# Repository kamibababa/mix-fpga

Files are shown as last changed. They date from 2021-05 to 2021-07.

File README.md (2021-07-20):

# MIX-fpga

Have you ever heard of Don Knuths (hypothetical) first polyunsaturated computer MIX, the 1009? In this project we will build a binary version of the MIX-Computer as described in "The Art of Computer Programming, Vol. 1" by Donald E. Knuth running on an fpga-board.

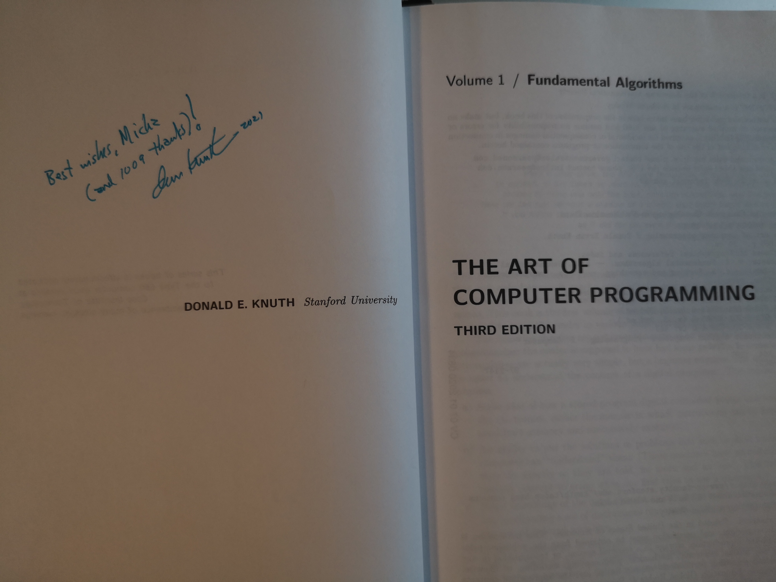
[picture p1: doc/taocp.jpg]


The presented implementation is based on the fpga development board iCE40HX8K-EVB from the company Olimex Ltd., which has the nice property of being completely open source. The whole project uses only FOSS free and open source hard- and software, so everybody can build their own MIX following the instructions in `build`.

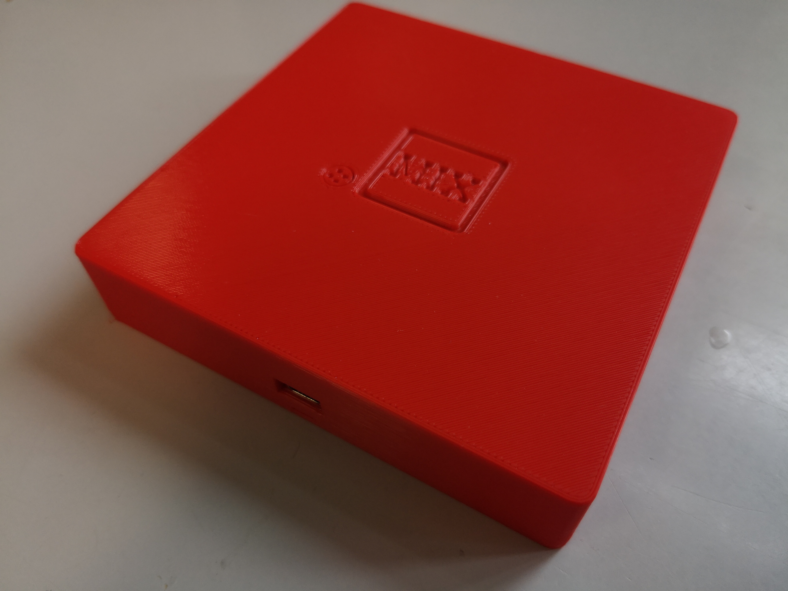
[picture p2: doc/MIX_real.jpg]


## A look Inside

The MIX computer is composed of two little boards:

1. iCE40HX8K-EVB, the fpga development board from olimex.com
2. USB-serial adapter. Used to power the board with 5V and to in-/output data over serial interface.

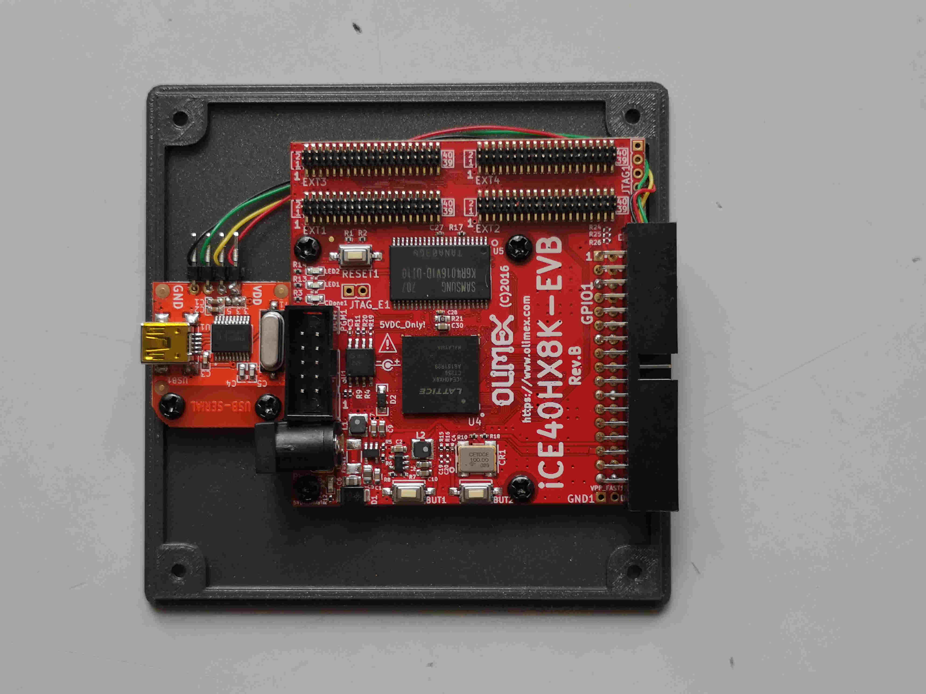
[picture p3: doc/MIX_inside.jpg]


### Basic unit of time
MIX runs on iCE40HX8K-EVB clocked at 23.8MHz. The basic unit of time 1u corresponds to 42ns, so according to Knuth it's a relatively high priced machine.

### Character based I/O units U16-U20
In our MIX implementation all character based I/O units (U16 -- U20) are connected to the USB-connector and can be accessed as serial data streams. You can connect MIX with any PC running a terminal emulator (e.g. screen for linux). The terminal should be set to 115200 baud (8N1). A conversion between ASCII and Knuths character codes is done in hardware according to Knuths specification (see TAOCP p. 128).

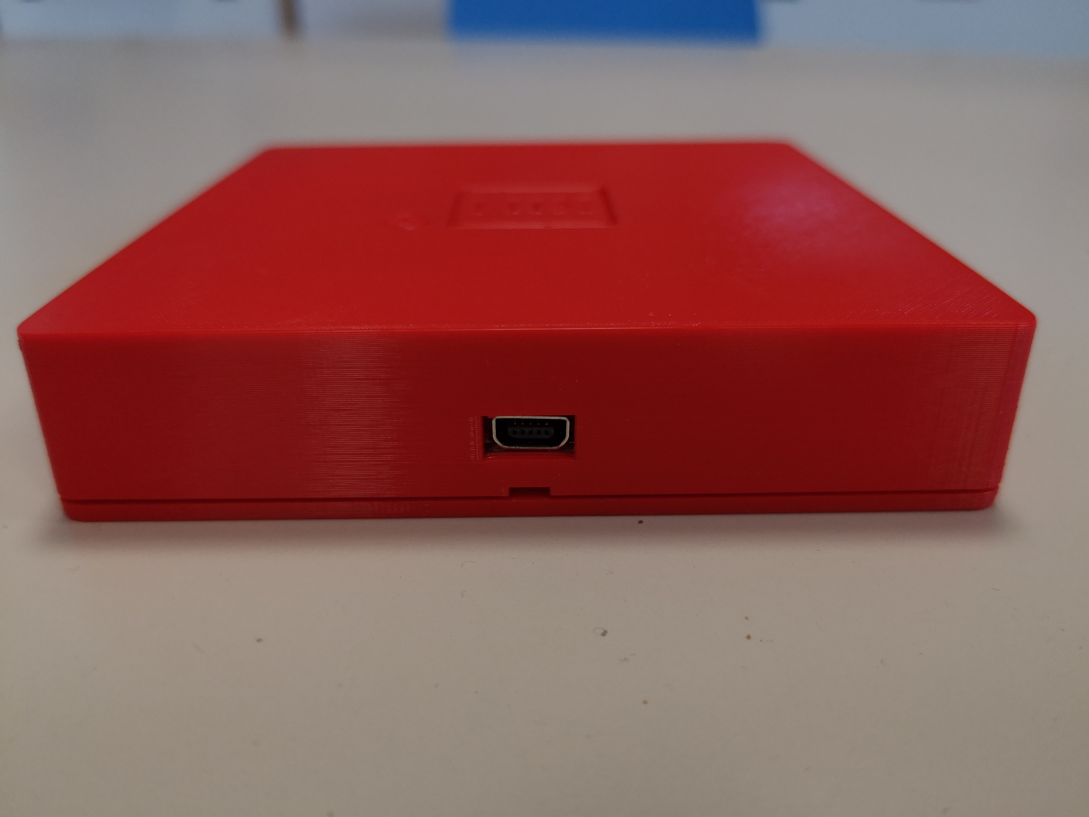
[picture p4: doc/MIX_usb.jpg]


### The block based I/O unit U0
A block based device is implemented on I/O unit 0. The device acts as a tape with 1024 blocks à 100 words. The data is stored in the SRAM chip included on the iCE40HX8K-EVB board. The speed of read and write operations is exactly 401u for reading or writing one complete block of data (no JBUS is needed). The data stored to unit U0 can be retrieved also after a reset (GO-Button). But on a full shutdown, when removing power supply (USB connector) data is lost.

### Commands
All commands described in TAOCP Vol. 1 are implemented (s. list) with execution times corresponding to Knuth's specifications. Special care is given to the correct timings. Even the "sofisticated" commands SRC and SLC, which need a modulo 10 computation are executed in the defined timing of two cycles.

| Command | OP  | Field | Timing |
| ---|-----|---|---|
| NOP | 0 | 0 | 1u |
| ADD, SUB, MUL, DIV | 1, 2, 3, 4 | 0:5 | 2u, 2u, 10u, 12u |
| FADD, FSUB, FMUL, FDIV | 1, 2, 3, 4 | 6 | 4u, 4u, 9u, 11u |
| NUM, CHAR| 5 | 0, 1 | 10u |
| HLT | 5 | 2 | ? |
| SLA, SRA, SLAX, SRAX, SLC, SRC| 6  | 0--5|  2u |
| MOVE | 7 | F | (1+2F)u|
| LDr | 8--15| 0:5 | 2u |
| LDNr |16--23| 0:5 | 2u |
| STr |24--31| 0:5 | 2u |
| STJ | 32  | 0:2 | 2u |
| STZ | 33  | 0:5 | 2u |
|JBUS, JRED|34,38| U | 1u |
| IOC | 35  | U | 1u |
| IN, OUT  |36,37| U | (1+T)u |
| JMP, JSJ, JOV, JNOV, JL, JE, JG, JGE, JNE, JLE| 39  |0--9  | 1u | 
| JrN, JrZ, JrP, JrNN, JrNZ, JrNP, JrE, JrO | 40--47| 0--7 | 1u |
| INCr, DECr, ENTr, ENNr  | 48--53 |0--3 | 1u |
| CMPr|54--63|0:5 | 2u |

The system can (easily) be extended in various ways:

1. add more commands:
	* logic operators: AND, OR, XOR, NOT (to do)
	* JrE,JrO jump if Register r is even/odd (done)
	* Floating point arithmetic: FADD, FSUB, FMUL, FDIV (done)
	* Floating point compare: FCMP (to do)
2. add more hardware:
	* add leds to run the traffic light example (done)
	* add block I/O unit (done)

### The GO button
MIX comes with the "GO button" attached to USB-UART. So after pressing the GO button MIX-programms can be uploaded by sending the "punched cards" to USB-UART.

### Toast case
MIX fits in a nice case with formfactor of a slice of toast, so your complete MIX computer system will easily fit into your lunch box. The case can be printed with a 3D printer. Design files can be found in the directory `build/toast`.

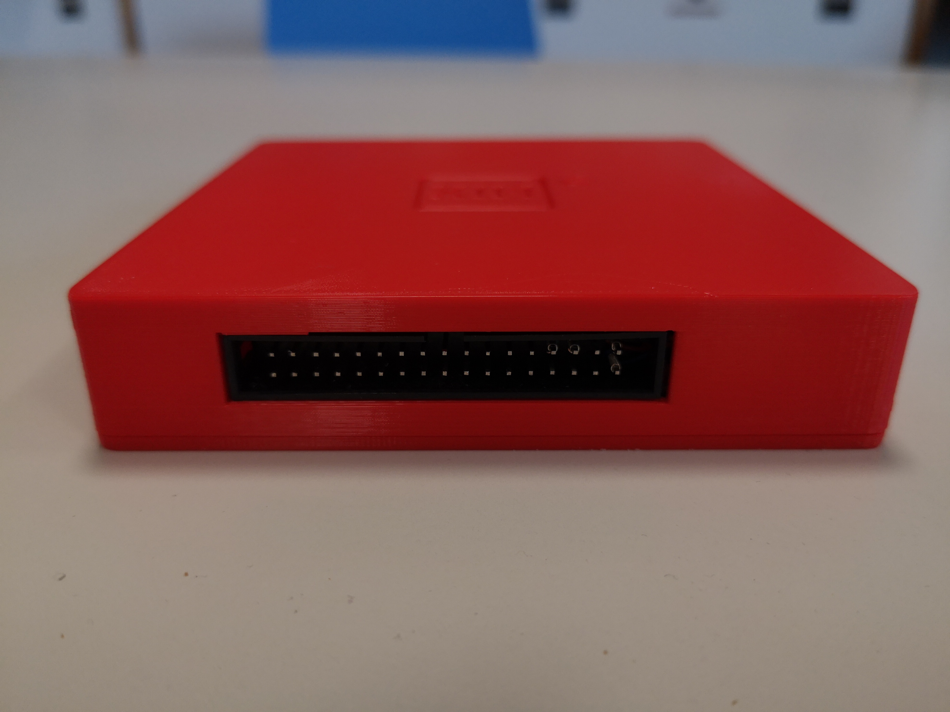
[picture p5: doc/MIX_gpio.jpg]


### Verify

MIX has been verified with the following programms. The numbering correspond to the sections in TAOCP.

* **1.3.1ex26** card-loading routine
* **1.3.2P** table of primes
* **1.3.2E** easter dates
* **1.3.2.ex13** cryptanalyst problem (classified)
* **1.3.2.ex16** sum of harmonic series
* **1.3.2.ex20** josephus problem
* **1.3.2.ex22** traffic signal problem (driving real LEDs)
* **1.3.3A** multiply permutations in cycle form
* **1.4.2**  character input routine
* **1.4.3** tracing routine (uses tape U0)
* **2.2.5elevator** elevator simulation (with added in-/output)
* **mixaload** A load and go assembler by James L. Peterson from [Computer Organization and Assembly Language Programming](http://www.jklp.org/profession/books/mix/index.html)

### Example 1: Program 1.3.2P
Compute the first 500 primes
	
```
FIRST FIVE HUNDRED PRIMES                                                 
     0002 0233 0547 0877 1229 1597 1993 2371 2749 3187                    
     0003 0239 0557 0881 1231 1601 1997 2377 2753 3191                    
     0005 0241 0563 0883 1237 1607 1999 2381 2767 3203                    
     0007 0251 0569 0887 1249 1609 2003 2383 2777 3209                    
     0011 0257 0571 0907 1259 1613 2011 2389 2789 3217                    
     0013 0263 0577 0911 1277 1619 2017 2393 2791 3221                    
     0017 0269 0587 0919 1279 1621 2027 2399 2797 3229                    
     0019 0271 0593 0929 1283 1627 2029 2411 2801 3251                    
     0023 0277 0599 0937 1289 1637 2039 2417 2803 3253                    
     0029 0281 0601 0941 1291 1657 2053 2423 2819 3257                    
     0031 0283 0607 0947 1297 1663 2063 2437 2833 3259                    
     0037 0293 0613 0953 1301 1667 2069 2441 2837 3271                    
     0041 0307 0617 0967 1303 1669 2081 2447 2843 3299                    
     0043 0311 0619 0971 1307 1693 2083 2459 2851 3301                    
     0047 0313 0631 0977 1319 1697 2087 2467 2857 3307                    
     0053 0317 0641 0983 1321 1699 2089 2473 2861 3313                    
     0059 0331 0643 0991 1327 1709 2099 2477 2879 3319                    
     0061 0337 0647 0997 1361 1721 2111 2503 2887 3323                    
     0067 0347 0653 1009 1367 1723 2113 2521 2897 3329                    
     0071 0349 0659 1013 1373 1733 2129 2531 2903 3331                    
     0073 0353 0661 1019 1381 1741 2131 2539 2909 3343                    
     0079 0359 0673 1021 1399 1747 2137 2543 2917 3347                    
     0083 0367 0677 1031 1409 1753 2141 2549 2927 3359                    
     0089 0373 0683 1033 1423 1759 2143 2551 2939 3361                    
     0097 0379 0691 1039 1427 1777 2153 2557 2953 3371                    
     0101 0383 0701 1049 1429 1783 2161 2579 2957 3373                    
     0103 0389 0709 1051 1433 1787 2179 2591 2963 3389                    
     0107 0397 0719 1061 1439 1789 2203 2593 2969 3391                    
     0109 0401 0727 1063 1447 1801 2207 2609 2971 3407                    
     0113 0409 0733 1069 1451 1811 2213 2617 2999 3413                    
     0127 0419 0739 1087 1453 1823 2221 2621 3001 3433                    
     0131 0421 0743 1091 1459 1831 2237 2633 3011 3449                    
     0137 0431 0751 1093 1471 1847 2239 2647 3019 3457                    
     0139 0433 0757 1097 1481 1861 2243 2657 3023 3461                    
     0149 0439 0761 1103 1483 1867 2251 2659 3037 3463                    
     0151 0443 0769 1109 1487 1871 2267 2663 3041 3467                    
     0157 0449 0773 1117 1489 1873 2269 2671 3049 3469                    
     0163 0457 0787 1123 1493 1877 2273 2677 3061 3491                    
     0167 0461 0797 1129 1499 1879 2281 2683 3067 3499                    
     0173 0463 0809 1151 1511 1889 2287 2687 3079 3511                    
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
```
			
### Example 2: Program 1.3.2.ex22
MIX can control the traffic signal of the corner del Mar Avenue/Berkeley Avenue. MIX is NOT a simulatin/emulation. It's real hardware. So you can drive the LEDs with the output of RegisterX. Input is done with a push button, which directly connects to the overflow toggle.

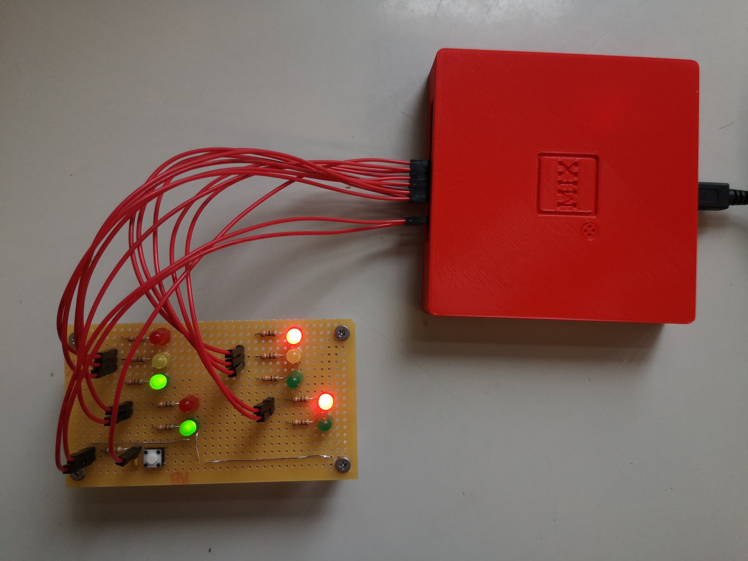
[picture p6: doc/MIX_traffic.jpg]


## need help?
In case you find encounter an issue with MIX`:

* don't panic
* send an email to mi.schroeder@netcologne.de

## related links

* [The Art of Computer Programming](https://www-cs-faculty.stanford.edu/~knuth/taocp.html): Donald Knuth's homepage

* [The Art of FPGAs: MIX-FPGA](https://www.hackster.io/news/the-art-of-fpgas-mix-fpga-edc1a7e47939): Article of Whitney Knitter on hackster.io

* [Computer Organization and Assembly Language Programming](http://www.jklp.org/profession/books/mix/index.html) by James L. Peterson

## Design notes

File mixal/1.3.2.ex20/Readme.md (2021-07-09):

# Running program t on MIX
We will run programm t of exercise 20 in chapter 1.3.2 TAOCP (p. 161) on MIX. Programm t controls the traffic signal at corner of Del Mare Boulevard and Berkeley Avenue. This project will connect LEDs directly to the register rX and a push button to the  Overflow toggle. This will be done extending the fpga design and routing the appropriate signals to the GPIO connector at the back of MIX.



## Extending the fpga desing
Make a copy of the folder `rtl` and cd into it.
```
cd build
cp -r rtl rtl_traffic_light
cd rtl_traffic_light
```
### mix.pcf
Add the following lines to physical constraint file `mix.pcf`:

```
#at the GPIO connector you find
set_io rx 		E4	# GPIO 5
set_io tx 		B2	# GPIO 7
set_io dmred 	F5	# GPIO 9
set_io bred 	J2	# GPIO 10
set_io dmamber 	B1	# GPIO 11
set_io bamber 	H1	# GPIO 12
set_io dmgreen 	C1	# GPIO 13
set_io bgreen 	G1	# GPIO 14
set_io dmdw 	C2	# GPIO 15
set_io bdw 		J5	# GPIO 16
set_io dmw 		F4	# GPIO 17
set_io bw 		H2	# GPIO 18
set_io button 	D2	# GPIO 19
```

### mix.v
Add the following lines to the hardware description file `mix.v` to connect the Register rX with the traffic signals.

```
	assign dmgreen = RegisterX[19:18] == 2'd1;
	assign dmamber = RegisterX[19:18] == 2'd2;
	assign dmred = RegisterX[19:18] == 2'd3;
	assign bgreen = RegisterX[13:12] == 2'd1;
	assign bamber = RegisterX[13:12] == 2'd2;
	assign bred = RegisterX[13:12] == 2'd3;
	assign dmw = RegisterX[7:6] == 2'd1;
	assign dmdw = RegisterX[7:6] == 2'd2;
	assign bw = RegisterX[1:0] == 2'd1;
	assign bdw = RegisterX[1:0] == 2'd2;
```

Find the code snipped that controls the overflow toggle and add the line commented with "# traffic signal button". 

```
always @(posedge clk)
		if (reset) overflow <= 0;
		else if (button) overflow <= 1;		# traffic signal button
		else if (add2) overflow <= addof;
		else if (sub2) overflow <= subof;
		else if (ide) overflow <= (rA|rX)? ideout[30] : ideout[12];

```
### rebuild and flash to iCE40HX8K-EVB

* Rebuild the fpga project and upload. `apio clean` is needed, because otherwise the the preloaded memory will not be updated.
	```
	apio clean
	apio build -v
	apio upload
	```
	
	Tipp: change the welcome message to ensure the new rom file has been uploaded.
	
### leds and button
Connect leds and button (don't forget resistors) to the appropriate GPIO connectors as described in the `mix.pcf` file. For simplicity only one LED is shown below:

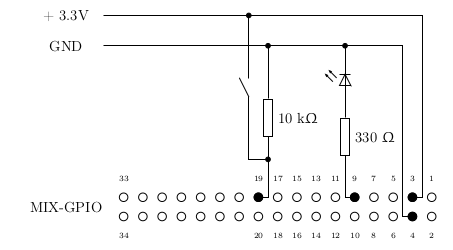
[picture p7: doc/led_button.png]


**Attention:** gpio pins 1,2,5 and 7 are already used by the internal USB-serial converter. 

### t.mixal
Compile t.mixal, upload to MIX and run the traffic signals.

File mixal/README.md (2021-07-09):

## Running programs on MIX

### tools
To run MIXAL programs on MIX the following tools found in `tools` are needed:

* `asm.py`: translates the mixal program into numeric representation (.mls).

* `mls2card.py` : translate the machine code (.mls) to punchcard format. The first two cards beeing the loading routine (1.3.1.ex26) and the last card beeing the transfer card.

* `mls2char.py` : translate to character codes, which can directly be read by MIX. (This is only necessary for the card-loading routine written on the first two punch cards).

* `mls2bin.py`: translate the .mls file to binary. This is only necessary for the GO button, which is hardcoded into fpga ROM.

### V1: Upload and run in a screen session
Finally you can connect your PC to MIX with a USB cable and start the  terminal emulator (```screen```):

```
$ screen /dev/ttyUSB0 115200
```

Press the GO button to start MIX. You should see the MIX welcome message:

```
WELCOME TO MIX. 1U = 40NS. U16-U20 TO UART @115200 BAUD (8N1).        
```

If `screen` does not open the terminal try with `sudo screen`. This might happen, when the user is not allowed to acces the device `/dev/ttyUSB0`. Check the user setting of `/dev/ttyUSB0` and add the user to the dialout group `sudo usermod -a -G $USER dialout`.

Within  the screen session you can upload the mixal programs written on punch cards:

```
<ctrl-a> : readreg p p.card
<ctrl-a> : paste p
```

### V2: Upload and run using the Makefile
As an alterntive to `screen` you can send jobs to MIX using a `Makefile`. Every tested program comes in a subfolder with a corresponding \lstinline|Makefile|, which can be used to compile, upload, and run the program on MIX.

* Connect MIX to USB
* Press the GO button
* run the Makefile
* the output is stored in a .out file

```
$ make clean
$ make
```

## Example program 1.3.2P
We will run programm P of chapter 1.3.2 TAOCP (p. 148) on MIX. Programm P computes the first 500 primes and outputs them in a table on the line printer U19.

### p.mixal
The mixal program can be found in `mixal/1.3.2P/p.mixal`. Inpect the file with:

```
$ cd mixal/1.3.2P
$ cat p.mixal
```

```
* EXAMPLE PROGRAM ... TABLE OF PRIMES                                           
*                                                                               
L          EQU  500                                                             
PRINTER    EQU  18                                                              
PRIME      EQU  -1                                                              
BUF0       EQU  2000                                                            
BUF1       EQU  BUF0+25                                                         
           ORIG 3000                                                            
START      IOC  0(PRINTER)                                                      
           LD1  =1-L=                                                           
           LD2  =3=                                                             
2H         INC1 1                                                               
           ST2  PRIME+L,1                                                       
           J1Z  2F                                                              
4H         INC2 2                                                               
           ENT3 2                                                               
6H         ENTA 0                                                               
           ENTX 0,2                                                             
           DIV  PRIME,3                                                         
           JXZ  4B                                                              
           CMPA PRIME,3                                                         
           INC3 1                                                               
           JG   6B                                                              
           JMP  2B                                                              
2H         OUT  TITLE(PRINTER)                                                  
           ENT4 BUF1+10                                                         
           ENT5 -50                                                             
2H         INC5 L+1                                                             
4H         LDA  PRIME,5                                                         
           CHAR                                                                 
           STX  0,4(1:4)                                                        
           DEC4 1                                                               
           DEC5 50                                                              
           J5P  4B                                                              
           OUT  0,4(PRINTER)                                                    
           LD4  24,4                                                            
           J5N  2B                                                              
           HLT                                                                  
* INITIAL CONTENTS OF TABLES AND BUFFERS                                        
           ORIG PRIME+1                                                         
           CON  2                                                               
           ORIG BUF0-5                                                          
TITLE      ALF  FIRST                                                           
           ALF   FIVE                                                           
           ALF   HUND                                                           
           ALF  RED P                                                           
           ALF  RIMES                                                           
           ORIG BUF0+24                                                         
           CON  BUF1+10                                                         
           ORIG BUF1+24                                                         
           CON  BUF0+10                                                         
           END  START                                                           
```

### p.mls
First we translate the mixal programm to binary code. This is done with the translator ```tools/asm.py```

```
$ ../tools/asm.py p.mixal
$ cat p.mls
```

```
                     0001 * EXAMPLE PROGRAM ... TABLE OF PRIMES
                     0002 *
                     0003 L          EQU  500 
                     0004 PRINTER    EQU  18 
                     0005 PRIME      EQU  -1 
                     0006 BUF0       EQU  2000 
                     0007 BUF1       EQU  BUF0+25 
                     0008            ORIG 3000 
3000 + 0000 00 18 35 0009 START      IOC  0(PRINTER) 
3001 + 2050 00 05 09 0010            LD1  =1-L= 
3002 + 2051 00 05 10 0011            LD2  =3= 
3003 + 0001 00 00 49 0012 2H@0012    INC1 1 
3004 + 0499 01 05 26 0013            ST2  PRIME+L,1 
3005 + 3016 00 01 41 0014            J1Z  2F 
3006 + 0002 00 00 50 0015 4H@0015    INC2 2 
3007 + 0002 00 02 51 0016            ENT3 2 
3008 + 0000 00 02 48 0017 6H@0017    ENTA 0 
3009 + 0000 02 02 55 0018            ENTX 0,2 
3010 - 0001 03 05 04 0019            DIV  PRIME,3 
3011 + 3006 00 01 47 0020            JXZ  4B 
3012 - 0001 03 05 56 0021            CMPA PRIME,3 
3013 + 0001 00 00 51 0022            INC3 1 
3014 + 3008 00 06 39 0023            JG   6B 
3015 + 3003 00 00 39 0024            JMP  2B 
3016 + 1995 00 18 37 0025 2H@0025    OUT  TITLE(PRINTER) 
3017 + 2035 00 02 52 0026            ENT4 BUF1+10 
3018 - 0050 00 02 53 0027            ENT5 -50 
3019 + 0501 00 00 53 0028 2H@0028    INC5 L+1 
3020 - 0001 05 05 08 0029 4H@0029    LDA  PRIME,5 
3021 + 0000 00 01 05 0030            CHAR  
3022 + 0000 04 12 31 0031            STX  0,4(1:4) 
3023 + 0001 00 01 52 0032            DEC4 1 
3024 + 0050 00 01 53 0033            DEC5 50 
3025 + 3020 00 02 45 0034            J5P  4B 
3026 + 0000 04 18 37 0035            OUT  0,4(PRINTER) 
3027 + 0024 04 05 12 0036            LD4  24,4 
3028 + 3019 00 00 45 0037            J5N  2B 
3029 + 0000 00 02 05 0038            HLT   
                     0039 * INITIAL CONTENTS OF TABLES AND BUFFERS
                     0040            ORIG PRIME+1 
0000 + 0000 00 00 02 0041            CON  2 
                     0042            ORIG BUF0-5 
1995 + 0393 19 22 23 0043 TITLE      ALF  FIRST
1996 + 0006 09 25 05 0044            ALF   FIVE
1997 + 0008 24 15 04 0045            ALF   HUND
1998 + 1221 04 00 17 0046            ALF  RED P
1999 + 1225 14 05 22 0047            ALF  RIMES
                     0048            ORIG BUF0+24 
2024 + 0000 00 31 51 0049            CON  BUF1+10 
                     0050            ORIG BUF1+24 
2049 + 0000 00 31 26 0051            CON  BUF0+10 
2050 - 0000 00 07 51      =1-L       CON  499
2051 + 0000 00 00 03      =3         CON  3
                     0052            END  START 
                                     TRANS 3000
                          * SYMBOL TABLE
                          *          EQU  2050
                          L          EQU  500
                          PRINTER    EQU  18
                          PRIME      EQU  -1
                          BUF0       EQU  2000
                          BUF1       EQU  2025
                          START      EQU  3000
                          2H@0012    EQU  3003
                          4H@0015    EQU  3006
                          6H@0017    EQU  3008
                          2H@0025    EQU  3016
                          2H@0028    EQU  3019
                          4H@0029    EQU  3020
                          TITLE      EQU  1995
                          =1-L       EQU  2050
                          =3         EQU  2051
```

### p.card

Next we must write the binary code onto punchcards. This can be done with the python script `tools/mls2card.py`. The python scripts reads the listing file `p.mls`, extracts the numeric codes and writes them in the file `p.card` in punched card format.

```
$ ../tools/mls2card.py p.mls 
$ cat p.card
```

Every line holds 80 chars of a punched card. The first two cards contain the bootloader discussed in exercise 26 in chapter 1.3.1 of TAOCP (see p. 510). The last card is the so called transfer card, which tells the bootloader to start execution at memory location 3000.

```
 O O6 Z O6    I C O4 0 EH A  F F CF 0  E   EU 0 IH G BB   EJ  CA. Z EU   EH E BA
   EU 2A-H S BB  C U 1AEH 2AEN V  E  ABG  CLU Z EH E BB J B. A  9               
     730000000001187053739552905376576740000262193013081429807906264090000524338
     73007000052446700000001760000008375000027475O0788004975000027480Q0000262195
     730140788529575078721847105229784690533463220001310738J0131334197000028295K
     730210000000069000001718300002622600013107317079167505300000175730006308172
     230280791412781000000013300000000000000000000000000000000000000000000000000
     100000000000002000000000000000000000000000000000000000000000000000000000000
     519950103101847000161133300021964200320094225032118408600000000000000000000
     120240000002035000000000000000000000000000000000000000000000000000000000000
     320490000002010000000049R00000000030000000000000000000000000000000000000000
TRANS030000000000000000000000000000000000000000000000000000000000000000000000000
```

### go!
Power MIX with USB cable connected to your computer.

Start a screen session with 115200 baud (8N1)
```
$ screen /dev/ttyUSB0 115200
```

Press the "Go button" on MIX

You should see the welcome message on your terminal:

```
WELCOME TO MIX. 1U = 30NS. U19 @115200 BAUD (8N1).                    
```

### Input the cards to U16
You can send the punch cards to MIX within the screen terminal session.

1. Read cards into a screen-buffer (called p) 
	```
	<in screen terminal> Ctr-a : readreg p p.card <enter>
	```

2. Send buffer to MIX
	```
	<in screen terminal> Ctrl-a : paste p <enter>
	```

After a few nanoseconds MIX spits out the following table to U19:

```
FIRST FIVE HUNDRED PRIMES                                                                                               
     3000 0233 0547 0877 1229 1597 1993 2371 2749 3187                                                                  
     0003 0239 0557 0881 1231 1601 1997 2377 2753 3191                                                                  
     0005 0241 0563 0883 1237 1607 1999 2381 2767 3203                                                                  
     0007 0251 0569 0887 1249 1609 2003 2383 2777 3209                                                                  
     0011 0257 0571 0907 1259 1613 2011 2389 2789 3217                                                                  
     0013 0263 0577 0911 1277 1619 2017 2393 2791 3221                                                                  
     0017 0269 0587 0919 1279 1621 2027 2399 2797 3229                                                                  
     0019 0271 0593 0929 1283 1627 2029 2411 2801 3251                                                                  
     0023 0277 0599 0937 1289 1637 2039 2417 2803 3253                                                                  
     0029 0281 0601 0941 1291 1657 2053 2423 2819 3257                                                                  
     0031 0283 0607 0947 1297 1663 2063 2437 2833 3259                                                                  
     0037 0293 0613 0953 1301 1667 2069 2441 2837 3271                                                                  
     0041 0307 0617 0967 1303 1669 2081 2447 2843 3299                                                                  
     0043 0311 0619 0971 1307 1693 2083 2459 2851 3301                                                                  
     0047 0313 0631 0977 1319 1697 2087 2467 2857 3307                                                                  
     0053 0317 0641 0983 1321 1699 2089 2473 2861 3313                                                                  
     0059 0331 0643 0991 1327 1709 2099 2477 2879 3319                                                                  
     0061 0337 0647 0997 1361 1721 2111 2503 2887 3323                                                                  
     0067 0347 0653 1009 1367 1723 2113 2521 2897 3329                                                                  
     0071 0349 0659 1013 1373 1733 2129 2531 2903 3331                                                                  
     0073 0353 0661 1019 1381 1741 2131 2539 2909 3343                                                                  
     0079 0359 0673 1021 1399 1747 2137 2543 2917 3347                                                                  
     0083 0367 0677 1031 1409 1753 2141 2549 2927 3359                                                                  
     0089 0373 0683 1033 1423 1759 2143 2551 2939 3361                                                                  
     0097 0379 0691 1039 1427 1777 2153 2557 2953 3371                                                                  
     0101 0383 0701 1049 1429 1783 2161 2579 2957 3373                                                                  
     0103 0389 0709 1051 1433 1787 2179 2591 2963 3389                                                                  
     0107 0397 0719 1061 1439 1789 2203 2593 2969 3391                                                                  
     0109 0401 0727 1063 1447 1801 2207 2609 2971 3407                                                                  
     0113 0409 0733 1069 1451 1811 2213 2617 2999 3413                                                                  
     0127 0419 0739 1087 1453 1823 2221 2621 3001 3433                                                                  
     0131 0421 0743 1091 1459 1831 2237 2633 3011 3449                                                                  
     0137 0431 0751 1093 1471 1847 2239 2647 3019 3457                                                                  
     0139 0433 0757 1097 1481 1861 2243 2657 3023 3461                                                                  
     0149 0439 0761 1103 1483 1867 2251 2659 3037 3463                                                                  
     0151 0443 0769 1109 1487 1871 2267 2663 3041 3467                                                                  
     0157 0449 0773 1117 1489 1873 2269 2671 3049 3469                                                                  
     0163 0457 0787 1123 1493 1877 2273 2677 3061 3491                                                                  
     0167 0461 0797 1129 1499 1879 2281 2683 3067 3499                                                                  
     0173 0463 0809 1151 1511 1889 2287 2687 3079 3511                                                                  
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
```
#### Using the Makefile
With the included Makefile the above described steps can be done in one pass:

* Connect MIX to USB
* Press the GO button
* run the Makefile: ```$ make```
* the output is stored in a `p.out` file

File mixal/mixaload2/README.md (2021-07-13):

## A load and go assembler for MIX
We will run the one pass load and go assembler program `mixaload.mixal` written by James L. Peterson in his book [Computer Organisation and Assembly Language Programming](http://www.jklp.org/profession/books/index.html).

`mixaload.mixal` consists of two parts:

1. Assembler
2. Loader

The assembler reads the card deck. The mixal program written on cards is then assembled to binary form and written to tape 0. After the assembler processes the last card with the tag `END` the loader takes on execution. It reads the content of tape 0 and writes the binary code to MIX main memory. When input on tape 0 is finished, execution is startet in main memory at the location described by `END xxxx`.

The only restriction imposed on the mixal program to be processed by this load and go assembler is: Don't use memory location 3700--3999, because that's where the loader routine resides in memory.

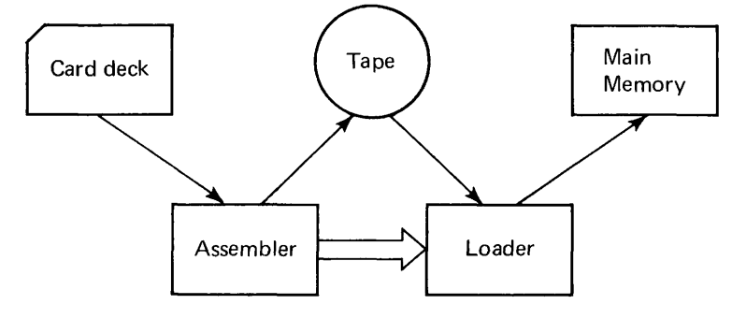
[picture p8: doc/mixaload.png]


### Example: mixaload processes program p
We will run the load and go assembler program `mixaload.mixal` on MIX. Then we will input `p.mixal` so MIX will assemble program p and finally execute it.

``` 
$ make clean
$ make
```

The output `mixaload.out` shows the result of the load and go assembler processing program p.

```
                              * TABLE OF PRIMES                                                                    1    
                 +0000000764  L          EQU  500                                                                  2    
                 +0000000022  PRINTER    EQU  18                                                                   3    
                 -0000000001  PRIME      EQU  -1                                                                   4    
                 +0000003720  BUF0       EQU  2000                                                                 5    
                 +0000003751  BUF1       EQU  BUF0+25                                                              6    
       +0000           +5670             ORIG 3000                                                                 7    
       +5670     -0000000763  C1         CON  1-L                                                                  8    
       +5671     +0000000003  C3         CON  3                                                                    9    
       +5672  +5670 00 05 11  START      LD1  C1                                                                  10    
       +5673  +5671 00 05 12             LD2  C3                                                                  11    
       +5674  +0001 00 00 61  H21        INC1 1                                                                   12    
       +5675  +0763 01 05 32             ST2  PRIME+L,1                                                           13    
       +5676  +7777 00 01 51             J1Z  H22                                                                 14    
       +5677  +0002 00 00 62  H41        INC2 2                                                                   15    
       +5700  +0002 00 02 63             ENT3 2                                                                   16    
       +5701  +0000 00 02 60  H61        ENTA 0                                                                   17    
       +5702  +0000 02 02 67             ENTX 0,2                                                                 18    
       +5703  -0001 03 05 04             DIV  PRIME,3                                                             19    
       +5704  +5677 00 01 57             JXZ  H41                                                                 20    
       +5705  -0001 03 05 70             CMPA PRIME,3                                                             21    
       +5706  +0001 00 00 63             INC3 1                                                                   22    
       +5707  +5701 00 06 47             JG   H61                                                                 23    
       +5710  +5674 00 00 47             JMP  H21                                                                 24    
       +5711  +7777 00 22 45  H22        OUT  TITLE(PRINTER)                                                      25    
       +5712  +3763 00 02 64             ENT4 BUF1+10                                                             26    
       +5713  -0062 00 02 65             ENT5 -50                                                                 27    
       +5714  +0765 00 00 65  H23        INC5 L+1                                                                 28    
       +5715  -0001 05 05 10  H42        LDA  PRIME,5                                                             29    
       +5716  +0000 00 01 05             CHAR                                                                     30    
       +5717  +0000 04 14 37             STX  0,4(1:4)                                                            31    
       +5720  +0001 00 01 64             DEC4 1                                                                   32    
       +5721  +0062 00 01 65             DEC5 50                                                                  33    
       +5722  +5715 00 02 55             J5P  H42                                                                 34    
       +5723  +0000 04 22 45             OUT  0,4(PRINTER)                                                        35    
       +5724  +0030 04 05 14             LD4  24,4                                                                36    
       +5725  +5714 00 00 55             J5N  H23                                                                 37    
       +5726  +0000 00 02 05             HLT                                                                      38    
       +5727           -0000             ORIG PRIME+1                                                             39    
       -0000     +0000000002             CON  2                                                                   40    
       +0001           +3713             ORIG BUF0-5                                                              41    
       +3713     +0611232627  TITLE      ALF  FIRST                                                               42    
       +3714     +0006113105             ALF   FIVE                                                               43    
       +3715     +0010301704             ALF   HUND                                                               44    
       +3716     +2305040021             ALF  RED P                                                               45    
       +3717     +2311160526             ALF  RIMES                                                               46    
       +3720           +3750             ORIG BUF0+24                                                             47    
       +3750     +0000003763             CON  BUF1+10                                                             48    
       +3751           +4001             ORIG BUF1+24                                                             49    
       +4001     +0000003732             CON  BUF0+10                                                             50    
       +4002           +5672             END  START                                                               51    
FIRST FIVE HUNDRED PRIMES                                                                                               
     0002 0233 0547 0877 1229 1597 1993 2371 2749 3187                                                                  
     0003 0239 0557 0881 1231 1601 1997 2377 2753 3191                                                                  
     0005 0241 0563 0883 1237 1607 1999 2381 2767 3203                                                                  
     0007 0251 0569 0887 1249 1609 2003 2383 2777 3209                                                                  
     0011 0257 0571 0907 1259 1613 2011 2389 2789 3217                                                                  
     0013 0263 0577 0911 1277 1619 2017 2393 2791 3221                                                                  
     0017 0269 0587 0919 1279 1621 2027 2399 2797 3229                                                                  
     0019 0271 0593 0929 1283 1627 2029 2411 2801 3251                                                                  
     0023 0277 0599 0937 1289 1637 2039 2417 2803 3253                                                                  
     0029 0281 0601 0941 1291 1657 2053 2423 2819 3257                                                                  
     0031 0283 0607 0947 1297 1663 2063 2437 2833 3259                                                                  
     0037 0293 0613 0953 1301 1667 2069 2441 2837 3271                                                                  
     0041 0307 0617 0967 1303 1669 2081 2447 2843 3299                                                                  
     0043 0311 0619 0971 1307 1693 2083 2459 2851 3301                                                                  
     0047 0313 0631 0977 1319 1697 2087 2467 2857 3307                                                                  
     0053 0317 0641 0983 1321 1699 2089 2473 2861 3313                                                                  
     0059 0331 0643 0991 1327 1709 2099 2477 2879 3319                                                                  
     0061 0337 0647 0997 1361 1721 2111 2503 2887 3323                                                                  
     0067 0347 0653 1009 1367 1723 2113 2521 2897 3329                                                                  
     0071 0349 0659 1013 1373 1733 2129 2531 2903 3331                                                                  
     0073 0353 0661 1019 1381 1741 2131 2539 2909 3343                                                                  
     0079 0359 0673 1021 1399 1747 2137 2543 2917 3347                                                                  
     0083 0367 0677 1031 1409 1753 2141 2549 2927 3359                                                                  
     0089 0373 0683 1033 1423 1759 2143 2551 2939 3361                                                                  
     0097 0379 0691 1039 1427 1777 2153 2557 2953 3371                                                                  
     0101 0383 0701 1049 1429 1783 2161 2579 2957 3373                                                                  
     0103 0389 0709 1051 1433 1787 2179 2591 2963 3389                                                                  
     0107 0397 0719 1061 1439 1789 2203 2593 2969 3391                                                                  
     0109 0401 0727 1063 1447 1801 2207 2609 2971 3407                                                                  
     0113 0409 0733 1069 1451 1811 2213 2617 2999 3413                                                                  
     0127 0419 0739 1087 1453 1823 2221 2621 3001 3433                                                                  
     0131 0421 0743 1091 1459 1831 2237 2633 3011 3449                                                                  
     0137 0431 0751 1093 1471 1847 2239 2647 3019 3457                                                                  
     0139 0433 0757 1097 1481 1861 2243 2657 3023 3461                                                                  
     0149 0439 0761 1103 1483 1867 2251 2659 3037 3463                                                                  
     0151 0443 0769 1109 1487 1871 2267 2663 3041 3467                                                                  
     0157 0449 0773 1117 1489 1873 2269 2671 3049 3469                                                                  
     0163 0457 0787 1123 1493 1877 2273 2677 3061 3491                                                                  
     0167 0461 0797 1129 1499 1879 2281 2683 3067 3499                                                                  
     0173 0463 0809 1151 1511 1889 2287 2687 3079 3511                                                                  
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

```

The first part of the output shows the result of the assembler processing the program p. Addresses and binary codes are represented in octal form.

The second part of the output shows the result of program p, which is loaded into memory by the loader and executed.

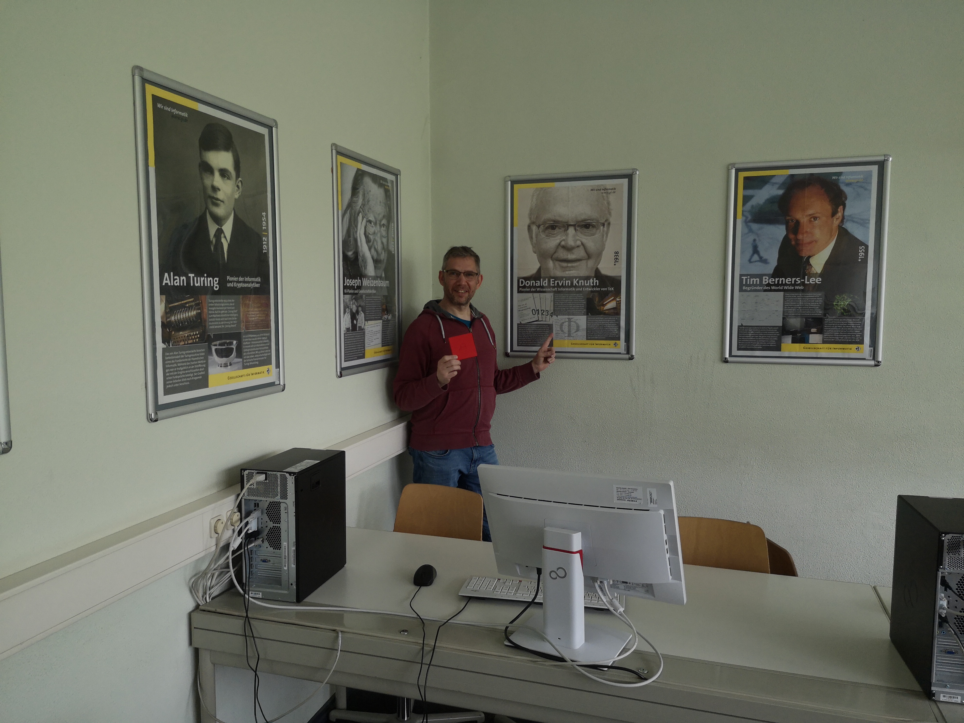
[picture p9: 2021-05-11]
doc/poster.jpg

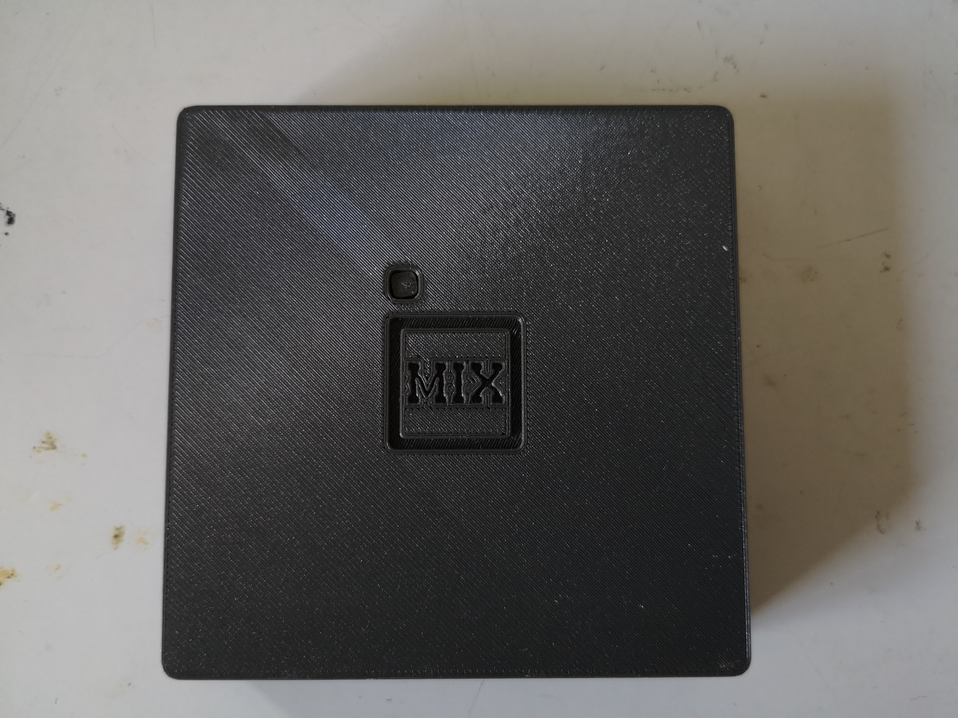
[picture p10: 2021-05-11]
doc/MIX_top.jpg

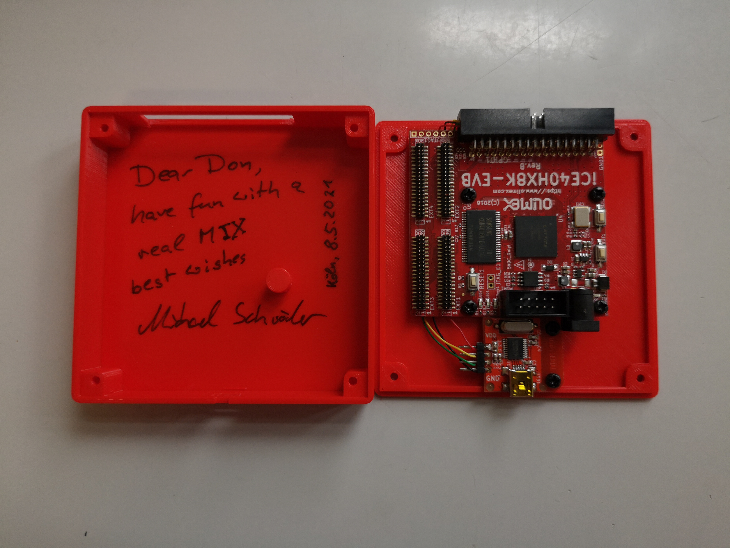
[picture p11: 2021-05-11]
doc/MIX_don.jpg

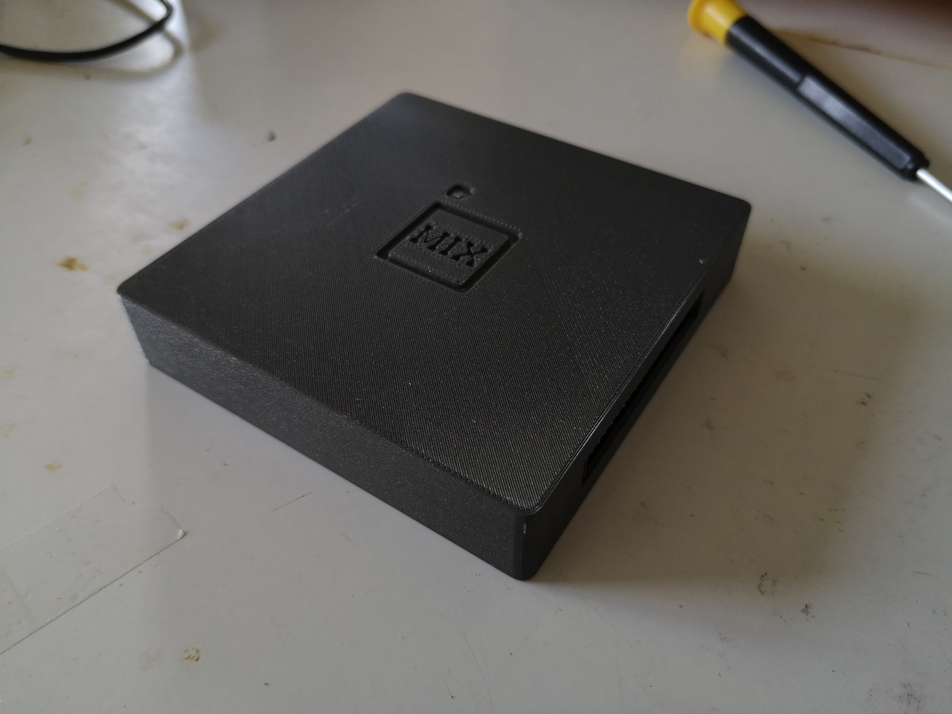
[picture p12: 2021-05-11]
doc/MIX_toast.jpg

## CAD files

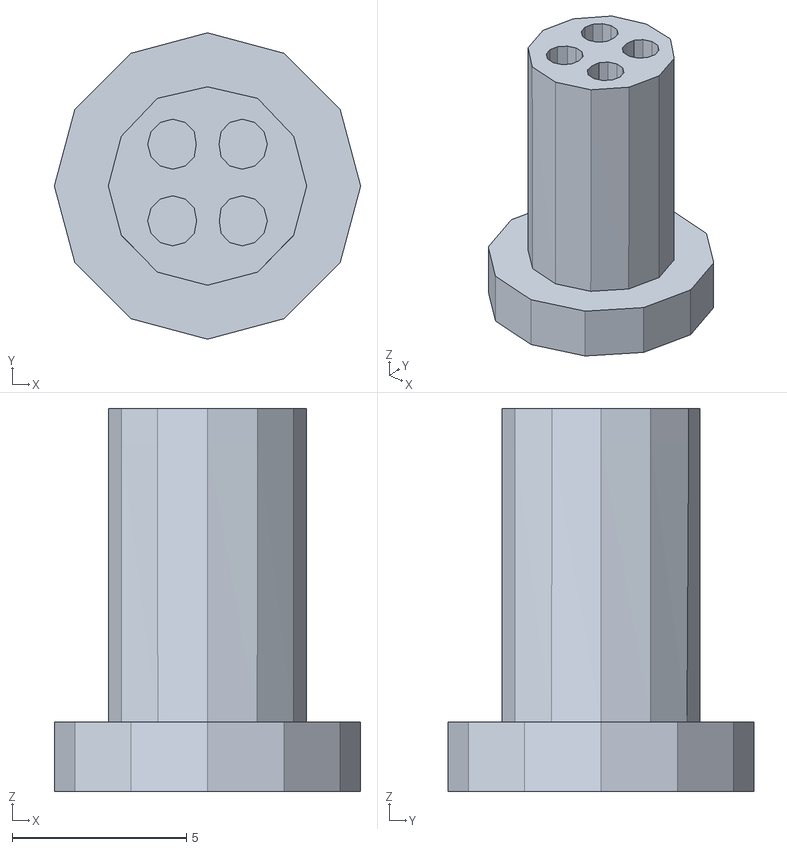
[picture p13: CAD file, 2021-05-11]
build/toast/go-Cube.stl
8.80 x 8.80 x 11.0

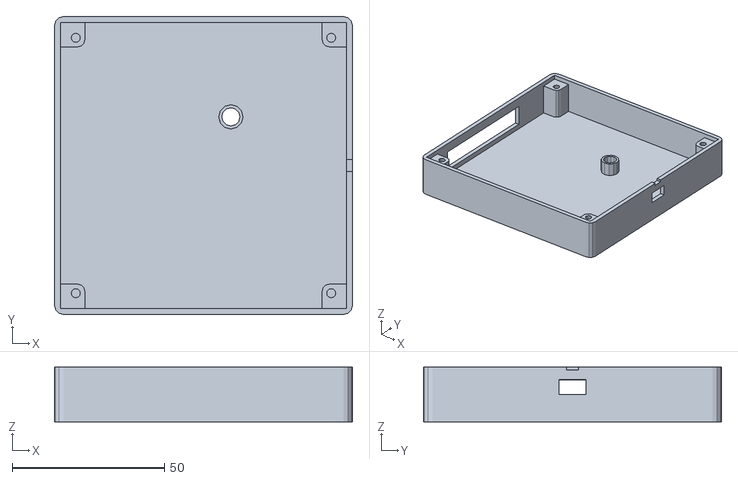
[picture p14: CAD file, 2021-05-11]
build/toast/top-Cube.stl
98.0 x 98.0 x 18.0

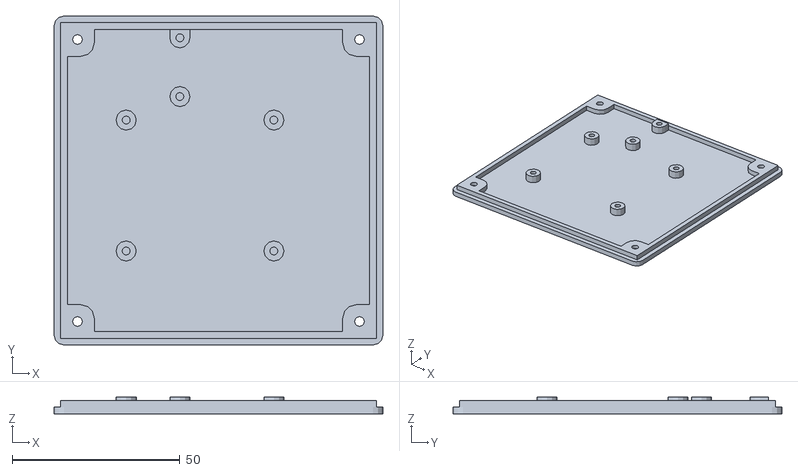
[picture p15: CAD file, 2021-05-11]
build/toast/bottom-Cube.stl
98.0 x 98.0 x 5.00

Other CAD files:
build/toast/bottom.blend
build/toast/go.blend
build/toast/top.blend

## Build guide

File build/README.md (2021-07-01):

## Build your own MIX and/or modify the fpga design

The project runs on iCE40HX8K-EVB fpga from Olimex Ltd. The whole project uses only FOSS soft- and hardware. With little modifications it should run on any fpga board available out in the wild.

### requirement
1. fpga board (iCE40HX8K-EVB), programmer device (Olimexino 32u4), idc10 cable (cable-IDC10) and USB-UART-board (BB-CH340T).  
Consider to buy at Olimex Ltd. https://www.olimex.com, the company with the highest number of registered OSHW-projects. To use Olimexino 32u4 as programmer for the fpga board, you first have to install `iceprogduino` (see. instructions on olimex.com).

	```
	$ cd build/iceprogduino
	$ make
	$ sudo make install
	```

2. fpga toolchain. The project was developed with apio (https://github.com/FPGAwars/apio), a free and open source software suite based on project icestorm (http://www.clifford.at/icestorm/) from Clifford Wolf.

	```
	$ sudo apt install python3 pip3
	$ sudo pip3 install -U apio
	$ apio install ice40
	$ apio install scons
	$ apio install iverilog
	$ apio install yosys
	$ sudo apt install gtkwave
	```

4.  install terminal program to connect to MIX over USB-UART.
5.  
	```
	$ sudo apt install screen
	```
	
### FPGA iCE40HX8K-EVB
Build the project and upload the circuit design to the fpga:

1. cd into the directory `rtl` and build the project

	```
	$ cd rtl
	$ apio clean
	$ apio build -v
	```
	
2. Connect the fpga board with olimexino-32u4 programmer. Use two USB cables to power both boards.

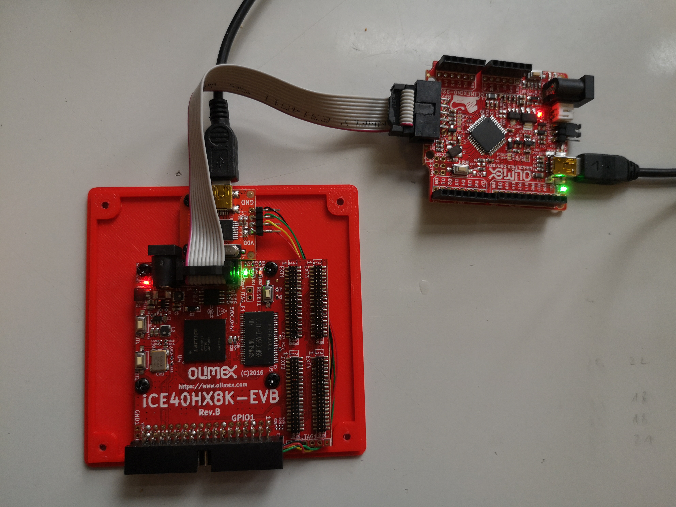
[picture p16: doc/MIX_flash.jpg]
 	

3. Upload the bitstream file to fpga board.

	```
	$ apio upload
	```

### serial adapter BB-CH340T
The serial adapter BB-CH340T is used to:

1. Power MIX with 5Volt from USB cable
2. Serial communication to MIX over I/O Unit 16-20.

To use USB-Serial adapter as power source we must do a little modification on the board:

1. cut with a cutter knife the connection marked in GREEN, and
2. solder a bridge BLACK between the right most terminal (VDD) and the 5V pad.

This will ensure that the right most terminal connector (red cable) get's 5Volt form USB, which will be used to power the fpga board. But the UART signals (green and yellow cables) are still leveled to 3.3V, which corresponds to the in-/output signal level of fpga-connector GPIO1.
	
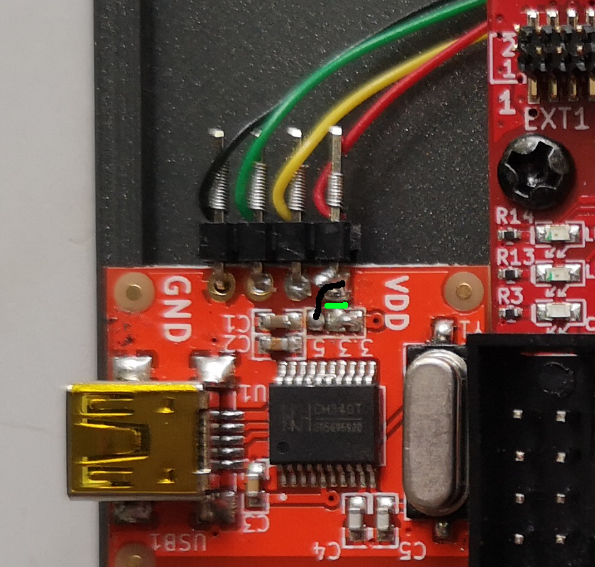
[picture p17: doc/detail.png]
 
 
The 4 wires are connected to the GPIO connector on the right side of iCE40HX8K-EVB according to the following table. Compare with schematic in `doc/iCE40HX8K-EVB_RevB.pdf` and `doc/bb_ch340t.png`.

| color  | USB-Serial  | GPIO (iCE40-HX8K-EVB)| 
|---|---|---|
| black  | GND | 2 |
| green  | RX | 7 |
| yellow | TX | 5 |
| red | VDD | 1 |

### GO button
We will implement the code needed by the GO button as proposed in  exercise 26 in chapter 1.3.1 of TAOCP (see p. 510).

#### prepare the software
The mixal program can be found in `go/go.mixal`. It starts at location 4000 (which is implemented in fpga but not used by MIX). The programm spits out the welcome message. The JMP instruction at memory cell 4095 will jmp to location 0000 and storing a +0000 in the J-Register, because beeing a binary version with 12 bit program counter the next execution address without the JMP instruction would equally yield 4095 + 0001 = 0000.

```
           ORIG 4000                                                            
           JMP  START                                                           
WELCOME    ALF  WELCO                                                           
           ALF  ME TO                                                           
           ALF   MIX.                                                           
           ALF   1U =                                                           
           ALF   42NS                                                           
           ALF  . U16                                                           
           ALF  -U20                                                            
           ALF  USB-U                                                           
           ALF  ART.                                                            
           ALF  U8 10                                                           
           ALF  00 BL                                                           
           ALF  OCKS.                                                           
           ALF   FPU.                                                           
           ORIG 4091                                                            
START      OUT  WELCOME(17)                                                     
           JBUS *(17)                                                           
NEXT       IN   0(16)                                                           
           JBUS *(16)                                                           
           JMP  0                                                               
           END  START                                                           
```

First we translate the mixal programm to binary code. This is done with the the assembler `mixal/tools/asm.py`.

```
$ ../../mixal/tools/asm.py go.mixal
$ cat go.mls
```

```
                     0001            ORIG 4000 
4000 + 4091 00 00 39 0002            JMP  START 
4001 + 1669 13 03 16 0003 WELCOME    ALF  WELCO
4002 + 0901 00 23 16 0004            ALF  ME TO
4003 + 0014 09 27 40 0005            ALF   MIX.
4004 + 0031 24 00 48 0006            ALF   1U =
4005 + 0034 32 15 22 0007            ALF   42NS
4006 + 2560 24 31 36 0008            ALF  . U16
4007 + 2904 32 30 00 0009            ALF  -U20 
4008 + 1558 02 45 24 0010            ALF  USB-U
4009 + 0083 23 40 00 0011            ALF  ART. 
4010 + 1574 00 31 30 0012            ALF  U8 10
4011 + 1950 00 02 13 0013            ALF  00 BL
4012 + 1027 12 22 40 0014            ALF  OCKS.
4013 + 0006 17 24 40 0015            ALF   FPU.
                     0016            ORIG 4091 
4091 + 4001 00 17 37 0017 START      OUT  WELCOME(17) 
4092 + 4092 00 17 34 0018            JBUS *(17) 
4093 + 0000 00 16 36 0019 NEXT       IN   0(16) 
4094 + 4094 00 16 34 0020            JBUS *(16) 
4095 + 0000 00 00 39 0021            JMP  0 
                     0022            END  START 
                                     TRANS 4091
                          * SYMBOL TABLE
                          *          EQU  4096
                          WELCOME    EQU  4001
                          START      EQU  4091
                          NEXT       EQU  4093
```

Next we must translate the binary code into a binary format readable by the fpga toolchain. This can be done with the python script `mixal/tools/mls2bin.py`.

```
$ ../../mixal/tools/mls2bin.py go.mls
```

The python scripts reads the listing file `go.mls`, extracts the code and writes it in the file `go.bin`.

Inspect the binary file `go.bin`

```
$ cat go.bin
```

```
0000000000000000000000000000000
0000000000000000000000000000000
0000000000000000000000000000000
...
...
0000000000000000000000000000000
0111110100001000000010011100101
0111111111100000000010011100010
0000000000000000000010000100100
0111111111110000000010000100010
0000000000000000000000000100111
```

The output contain the program code expressed as binary numbers. These binary numbers can be flashed to the iCE40HX8K-EVB board, so it's stored permanently in the MIX computer. At every reset (press GO button) the code will be executed. The first 4000 zero lines translate to NOP instructions. At the end you find the sequence IN(16),JBUS,JMP...

#### build fpga and flash to iCE40HX8K-EVB

* Copy the binary file into the directory `rtl`, where the fpga description files are.

	```
	$ cp go.bin ../rtl/go.bin
	```

* Rebuild the fpga project and upload. `apio clean` is needed, because otherwise the the preloaded memory will not be updated.
	```
	$ apio clean
	$ apio build -v
	$ apio upload
	```
	
	Tipp: change the welcome message to check if the new rom file has been uploaded.

### print toast case with a 3D printer
In the subfolder ```toast``` you find printing files for the case. The case consists of three parts:

* `bottom.blend`: the bottom part of the case
* `top.blend`: top part of case
* `go.blend`: go bottom

 	

### Example program 1.3.2.ex20T
We will run programm `mixal/1.3.2.ex20/t.mixal` of exercise 20 in chapter 1.3.2 TAOCP (p. 161) on MIX. Programm `t.mixal` controls the traffic signal at corner of Del Mare Boulevard and Berkeley Avenue. This project will connect LEDs directly to the register rX and a push button to the  Overflow toggle. This will be done extending the fpga design and routing the appropriate signals to the GPIO connector at the back of MIX.

 

#### Extending the fpga desing
Make a copy of the folder `build/rtl` and cd into it.

```
$ cd build
$ cp -r rtl rtl_traffic_light
$ cd rtl_traffic_light
```

#### mix.pcf

Find the following lines in the physical constraint file `mix.pcf´ and uncomment to get access to the GPIO pins 9-19.

```
#set_io dmred 	F5	# GPIO 9
#set_io bred 	J2	# GPIO 10
#set_io dmamber 	B1	# GPIO 11
#set_io bamber 	H1	# GPIO 12
#set_io dmgreen 	C1	# GPIO 13
#set_io bgreen 	G1	# GPIO 14
#set_io dmdw 	C2	# GPIO 15
#set_io bdw 		J5	# GPIO 16
#set_io dmw 		F4	# GPIO 17
#set_io bw 		H2	# GPIO 18
#set_io button 	D2	# GPIO 19
```

#### mix.v

To connect the Register rX with the traffic signals: find the following lines (28-38) in `mix.v´ and uncomment:

```
//	output wire dmgreen,
//	output wire dmamber,
//	output wire dmred,
//	output wire bgreen,
//	output wire bamber,
//	output wire bred,
//	output wire dmw,
//	output wire dmdw,
//	output wire bw,
//	output wire bdw,
//	input wire button,
	output wire hlt,
	output [17:0] sram_addr,
	inout [15:0] sram_data,
	output sram_cen,
	output sram_wen,
	output sram_oen

);
//	assign dmgreen = RegisterX[19:18] == 2'd1;
//	assign dmamber = RegisterX[19:18] == 2'd2;
//	assign dmred = RegisterX[19:18] == 2'd3;
//	assign bgreen = RegisterX[13:12] == 2'd1;
//	assign bamber = RegisterX[13:12] == 2'd2;
//	assign bred = RegisterX[13:12] == 2'd3;
//	assign dmw = RegisterX[7:6] == 2'd1;
//	assign dmdw = RegisterX[7:6] == 2'd2;
//	assign bw = RegisterX[1:0] == 2'd1;
//	assign bdw = RegisterX[1:0] == 2'd2;
```

Control the overflow toggle with the button by uncommenting line 239 in the code snippet:

```
	always @(posedge clk)
		if (reset|clearof) overflow <= 0;
//		else if (button) overflow <= 1;		//the traffic signal button controls the overflow toggle
		else if (add2 & addof) overflow <= 1;
		else if (div2 & divof) overflow <= 1;
		else if (ide & (rA|rX) & ideof) overflow <= 1;
		else if (fadd2 & faddof) overflow <= 1;
	       	else if (fmul2 & fmulof) overflow <=  1;
		else if (fdiv2 & fdivof) overflow <= 1;

```

####rebuild and flash to iCE40HX8K-EVB

Rebuild the fpga project and upload.

```
$ apio clean
$ apio upload -v
```

**Tipp:** change the welcome message to ensure the new rom file has been uploaded.

#### add leds and button to GPIO
Connect leds and button (don't forget resistors) to the appropriate GPIO connectors as described in the `mix.pcf´ file. For simplicity only one LED is shown below:

 

**Attention:** gpio pins 1,2,5 and 7 are already used by the internal USB-serial converter.

#### t.mixal
Compile and write `mixal/1.3.2.ex20/t.mixal` to puching card format. Start MIX by pressing the GO button. Upload `t.card` to MIX and see the traffic signals blinking.

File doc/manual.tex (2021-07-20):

\documentclass[a4paper,ngerman]{scrartcl}
\renewcommand{\rmdefault}{cmr}
\renewcommand{\sfdefault}{cmss}
\renewcommand{\ttdefault}{cmtt}
\usepackage[T1]{fontenc}
\usepackage[utf8]{inputenc}
\usepackage{array}
\usepackage{refstyle}
\usepackage{float}
\usepackage{enumitem}
\usepackage{amsmath}
%\usepackage{euler}
\usepackage{hyperref}
\makeatletter
\usepackage{multirow}
\usepackage{isotope}
\usepackage{tikz-uml}
\usepackage[section]{placeins}
\flushbottom
\usepackage{geometry}
\geometry{a4paper}
\usepackage{color}
\usepackage{tikz}
\usetikzlibrary{circuits.ee.IEC}
%\usepackage{beramono}
\usepackage{pdfpages}
\makeatother
%\usepackage{babel}
\usepackage{listings}
\lstset{language=verilog,
basicstyle={\footnotesize\fontfamily{fvm}\selectfont},
commentstyle={\textit},
keywordstyle={\bfseries},
tabsize=4,
frame=leftline,
numbers=left,
numberstyle={\tiny}}
\usepackage{siunitx}
\title{MIX-fpga}
\author{Michael Schröder \\ \href{mi.schroeder@netcologne.de}{mi.schroeder@netcologne.de}}
\usepackage[
type={CC},
modifier={by-nc-sa},
version={3.0},
]{doclicense}
\begin{document}

\maketitle

\section{A real MIX}

Have you ever heard of Don Knuths (hypothetical) first polyunsaturated computer MIX, the 1009? In this project we will build a binary version of the MIX-Computer as described in "The Art of Computer Programming, Vol. 1" by Donald E. Knuth running on an fpga-board.

\begin{figure}
	\centering
	
	
	\caption{A real MIX for Don Knuth}
	\label{fig:mixtoast}
\end{figure}

The presented implementation is based on the fpga development board iCE40HX8K-EVB from the company Olimex Ltd.\footnote{\href{www.olimex.com}{www.olimex.com}}, which has the nice property of being completely open source. The whole project uses only FOSS free and open source hard- and software, so everybody can build their own MIX following the instructions on the project site\footnote{\href{www.gitlab.com/x653/mix-fpga}{www.gitlab.com/x653/mix-fpga}}.

\subsection{A look inside}
The MIX computer is composed of two little boards:

\begin{enumerate}
	\item iCE40HX8K-EVB\footnote{\href{www.olimex.com/Products/FPGA/iCE40/iCE40HX8K-EVB}{www.olimex.com/Products/FPGA/iCE40/iCE40HX8K-EVB}}, the fpga development board from the company Olimex Ltd.	
	\item  USB-serial adapter\footnote{\href{www.olimex.com/Products/Breadboarding/BB-CH340T}{www.olimex.com/Products/Breadboarding/BB-CH340T}}. Used to power the board with 5V and to in-/output data over the serial interface.
\end{enumerate}

\begin{figure}
	\centering
	
	\caption{The two boards interconnected with wire wrap technique typical for computers of the 60s era}
	\label{fig:mixinside}
\end{figure}

\subsubsection{Basic unit of time}
MIX runs on iCE40HX8K-EVB clocked at \SI{23.8}{MHz}. The basic unit of time $u$ corresponds to $1u=\SI{42}{ns}$, so according to Knuth it's a relatively high priced machine.

\subsubsection{Character based I/O units U16-U20}
In our MIX implementation all character based I/O units (U16 -- U20) are connected to the USB-connector and can be accessed as serial data streams. You can connect MIX with any PC running a terminal emulator (e.g. screen for linux). The terminal should be set to 115200 baud (8N1). A conversion between ASCII and Knuths character codes is done in hardware according to Knuths specification (see TAOCP p. 128).

\subsubsection{The block based I/O unit U0}

A block based device is implemented on I/O unit 0. The device acts as a tape with 1024 blocks à 100 words. The data is stored in the SRAM chip included on the iCE40HX8K-EVB board. The speed of read and write operations is exactly $401 u$ for reading or writing one complete block of data (no \lstinline|JBUS| is needed). The data stored to unit U0 can be retrieved also after a reset (GO-Button). But on a full shutdown, when removing power supply (USB connector) data is lost.

\begin{figure}
	\centering
	
	
	
	\caption{All character based I/O is done through a USB to serial adapter @115200 baud (8N1). MIX can be expanded through a GPIO connector placed at the rear side }
	\label{fig:mixusb}
\end{figure}

\subsubsection{MIX commands}
All commands described in TAOCP Vol. 1 are implemented (s. table \ref{tab:commands} ) with execution times corresponding to Knuth's specifications. Special care is given to the correct timings. Even the "sofisticated" commands \lstinline|SRC| and \lstinline|SLC|, which need a modulo 10 computation are executed in the defined timing of two cycles.

\begin{table}
	\centering
	\label{tab:commands}
\caption{	MIX commands}
\begin{tabular}{|l|c|c|c|}

	\hline 
	\textbf{Command} & \textbf{OP} & \textbf{Field} & \textbf{Timing} \\ 
	\hline 
 \lstinline|NOP|     & 0   & 0     & $1u$     \\
	\hline 
 \lstinline|ADD|, \lstinline|SUB|, \lstinline|MUL|, \lstinline|DIV|     & 1, 2, 3, 4   & 0:5   & $2u$, $2u$, $10u$, $12u$     \\
 	\hline 
 \lstinline|FADD|, \lstinline|FSUB|, \lstinline|FMUL|, \lstinline|FDIV|   & 1, 2, 3, 4   & 6     & $4u$, $4u$, $9u$, $11u$     \\
 	\hline 
 \lstinline|NUM|, \lstinline|CHAR|& 5   & 0, 1   & $10u$    \\
 	\hline 
 \lstinline|HLT|     & 5   & 2     & $1u$ or $\infty$?   \\
 	\hline 
 \lstinline|SLA|, \lstinline|SRA|, \lstinline|SLAX|, \lstinline|SRAX|, \lstinline|SLC|, \lstinline|SRC|& 6  & 0---5&  $2u$     \\
 	\hline 
 \lstinline|MOVE|    & 7   & F     & $(1+2F)u$\\
 	\hline 
 \lstinline|LDr|, \lstinline|LDNr|    &16---23&0:5   & $2u$     \\
 	\hline 
 \lstinline|STr|     &24---31& 0:5   & $2u$     \\
 	\hline 
 \lstinline|STJ|     & 32  & 0:2   & $2u$     \\
 	\hline 
 \lstinline|STZ|     & 33  & 0:5   & $2u$     \\
	\hline 
\lstinline|JBUS|, \lstinline|JRED|&34,38& U     & $1u$     \\
	\hline 
 \lstinline|IOC|     & 35  & U     & $1u$     \\
	\hline 
 \lstinline|IN|, \lstinline|OUT|  &36,37& U     & $(1+T)u$ \\
	\hline 
\lstinline| JMP|, \lstinline|JSJ|, \lstinline|JOV|, \lstinline|JNOV|, \lstinline|JL|, \lstinline|JE|, \lstinline|JG|, \lstinline|JGE|, \lstinline|JNE|, \lstinline|JLE|& 39  &0---9  & $1u$   \\
 	\hline 
 \lstinline|JrN|, \lstinline|JrZ|, \lstinline|JrP|, \lstinline|JrNN|, \lstinline|JrNZ|, \lstinline|JrNP|, \lstinline|JrE|, \lstinline|JrO| & 40-47& 0---7 & 	$1u$ \\
	\hline 
 \lstinline|INCr|, \lstinline|DECr|, \lstinline|ENTr|, \lstinline|ENNr|  & 48---53   &0---3     & $1u$   \\
	\hline 
 \lstinline|CMPr| & 54---63&0:5          & $2u$   \\
	\hline 
\end{tabular} 
\end{table}

The system can (easily) be extended in various ways:

\begin{enumerate}
	\item add more commands:
	\begin{itemize}
		\item logic operators: \lstinline|AND|, \lstinline|OR|, \lstinline|XOR|, \lstinline|NOT|
		\item \lstinline|JrE|,\lstinline|JrO| jump if Register r is even/odd (done)
		\item Floating point arithmetic: \lstinline|FADD|, \lstinline|FSUB|, \lstinline|FMUL|, \lstinline|FDIV| (done)
		\item Floating point compare: \lstinline|FCMP| (to do)
	\end{itemize}
	\item add more hardware:
	\begin{itemize}
		\item add leds to run the traffic light example (s. chapter \ref{traffic} of this manual)
		\item add more I/O unit
	\end{itemize}
\end{enumerate}

\subsubsection{The GO button}
MIX comes with the \textit{GO button} attached to USB-UART. So after pressing the \textit{GO button} MIX-programms can be uploaded by sending the \textit{punched cards} to USB-UART.

\subsubsection{The toast case}
MIX comes in a nice case with formfactor of a slice of toast ($\SI{10}{cm} \times \SI{10}{cm} \times \SI{2}{cm}$), so your complete MIX computer system will easily fit into your lunch box. The case can be printed with a 3D printer. Design files can be found in the directory \lstinline|build/toast| of the project site.

\section{Running programs on MIX}
\subsection{tools}
To run mixal programs on your MIX the following tools found in \lstinline|mixal/tools| 
\footnote{\href{www.gitlab.com/x653/mix-fpga}{www.gitlab.com/x653/mix-fpga}} are needed:
\begin{itemize}
	\item \lstinline|asm.py|: translates the mixal program into numeric representation (\lstinline|.mls|).
	
	\item \lstinline|mls2card.py|: translate the machine code (\lstinline|.mls|) to punchcard format. The first two cards beeing the loading routine (1.3.1.ex26) and the last card beeing the transfer card.
	
	\item \lstinline|mls2char.py|: translate to character codes, which can directly be read by MIX. (This is only necessary for the card-loading routine written on the first two punch cards).
	
	\item \lstinline|mls2bin.py|: translate the \lstinline|.mls| file to binary. This is only necessary for the GO button, which is hardcoded into fpga ROM.	
\end{itemize}

\subsection{V1: upload and run in a screen session}
Finally you can connect your PC to MIX with a USB cable and start the  terminal emulator (\lstinline|screen|):

\begin{lstlisting}[numbers=none,frame=none]
$ screen /dev/ttyUSB0 115200
\end{lstlisting}

Press the \textit{GO button} to start MIX. You should see the MIX welcome message:

\begin{lstlisting}
WELCOME TO MIX. 1U = 40NS. U16-U20 TO UART @115200 BAUD (8N1).        
\end{lstlisting}

If \lstinline|screen| does not open the terminal try with \lstinline|sudo screen|. This might happen, when the user is not allowed to acces the device \lstinline|/dev/ttyUSB0|. Check the user setting of \lstinline|/dev/ttyUSB0| and add the user to the dialout group \lstinline|sudo usermod -a -G $USER dialout|.

Within  the screen session you can upload the mixal programs written on punch cards:
\begin{lstlisting}[language=bash,numbers=none,frame=none]
<ctrl-a> : readreg p p.card
<ctrl-a> : paste p
\end{lstlisting}

\subsection{V2: Upload and run using the Makefile}
As an alterntive to \lstinline|screen| you can send jobs to MIX using a \lstinline|Makefile|. Every tested program comes in a subfolder with a corresponding \lstinline|Makefile|, which can be used to compile, upload, and run the program on MIX.

\begin{itemize}
	\item Connect MIX to USB
	\item Press the GO button
	\item run the Makefile
	\item the output is stored in a \lstinline|.out| file
\end{itemize}

\begin{lstlisting}[numbers=none,frame=none]
$ make clean
$ make
\end{lstlisting}

\subsection{Verify}

MIX has been verified with the following programms. The numbering correspond to the sections in TAOCP.
\begin{itemize}	
\item \lstinline|1.3.1ex26| card-loading routine
\item \lstinline|1.3.2P| table of primes
\item \lstinline|1.3.2E| easter dates
\item \lstinline|1.3.2.ex13| cryptanalyst problem (classified)
\item \lstinline|1.3.2.ex16| sum of harmonic series
\item \lstinline|1.3.2.ex20| josephus problem
\item \lstinline|1.3.2.ex22| traffic signal problem (driving real LEDs)
\item \lstinline|1.3.3A| multiply permutations in cycle form
\item \lstinline|1.4.2|  character input routine
\item \lstinline|1.4.3|  trace routine (uses tape U0)
\item \lstinline|2.2.5elevator| elevator simulation (with added in-/output)
\item \lstinline|mixaload| A load and go assembler by James L. Peterson from "Computer Organization and Assembly Language Programming" \footnote{\href{http://www.jklp.org/profession/books/mix/index.html}{http://www.jklp.org/profession/books/mix/index.html}}

\end{itemize}

\section{Example program 1.3.2P}

We will run programm \lstinline|P| of chapter 1.3.2 TAOCP (p. 148) on MIX. Programm \lstinline|P| computes the first 500 primes and outputs them in a table on the line printer U18.

\subsection{Prepare the input}
\subsubsection{p.mixal}
The mixal program can be found in \lstinline|mixal/1.3.2P/p.mixal|:

\begin{lstlisting}[numbers=none,frame=none]
$ cd mixal/1.3.2P
$ cat p.mixal
\end{lstlisting}

\lstinputlisting{../mixal/1.3.2P/p.mixal}

\subsubsection{p.mls}
First we translate the mixal programm to binary code. This is done with the translator \lstinline|tools/asm.py|.

\begin{lstlisting}[numbers=none,frame=none]
$ ../tools/asm.py p.mixal
$ cat p.mls
\end{lstlisting}

\lstinputlisting{../mixal/1.3.2P/p.mls}

\subsubsection{p.card}
Next we must write the binary code onto punched cards. This can be done with the python script \lstinline|mixal/tools/mls2card.py|.
The python scripts reads the listing file \lstinline|p.mls|, extracts the numeric codes and writes them in the file \lstinline|p.card| in puncher card format.

Every line of \lstinline|p.card| holds 80 chars of a card. The first two cards contain the card loading routine discussed in exercise 26 in chapter 1.3.1 of TAOCP. The last card is the so called transfer card, which tells the bootloader to start execution at memory location 3000.

\begin{lstlisting}[numbers=none,frame=none]
$ ../tools/mls2card.py p.mls
$ cat p.card
\end{lstlisting}

\lstinputlisting{../mixal/1.3.2P/p.card}

\subsubsection{go!}
Power MIX with USB cable connected to your computer.
Start a screen session with 115200 baud (8N1)
\begin{lstlisting}[numbers=none,frame=none]
screen /dev/ttyUSB0 115200
\end{lstlisting}

Press the \textit{GO button} on MIX. You should see the welcome message on your terminal:
\begin{lstlisting}
WELCOME TO MIX. 1U = 40NS. U19 @115200 BAUD (8N1).                    
\end{lstlisting}

\subsubsection{input the cards to U16}
You can now send the punched cards to MIX within the screen terminal session.
Read cards into a screen-buffer (called p) and send the buffer to MIX.

\begin{lstlisting}[numbers=none,frame=none]
<in screen terminal> Ctr-a : readreg p p.card <enter>
<in screen terminal> Ctrl-a : paste p <enter>
\end{lstlisting}

After a short amount of time MIX spits out the following table to the printer U18. Notice that output to U18 have 120 characters per line, while output to the terminal U19 is only 70 chars wide.

\lstinputlisting{../mixal/1.3.2P/p.out}

\subsection{Congratulation}
You have run your first program on a \textit{real} MIX.

\subsection{Using Makefile}
With the included \lstinline|Makefile| the above described steps can be done in one pass:

\begin{itemize}
	\item Connect MIX to USB
	\item Press the GO button
	\item run the Makefile: \lstinline|$ make|
	\item the output is stored in \lstinline|p.out| file
\end{itemize}

\section{Build your own MIX and/or modify the fpga design}

The project runs on iCE40HX8K-EVB fpga from Olimex Ltd. The whole project uses only FOSS soft- and hardware. With little modifications it should run on any fpga board available out in the wild.

\subsection{Requirement}
\begin{enumerate}
	\item 
	fpga board (iCE40HX8K-EVB)
	\item programmer device (Olimexino 32u4) with idc10 cable (cable-IDC10)
	\item USB-UART-board (BB-CH340T).  
	\item fpga toolchain. The project was developed with \lstinline|apio| \footnote{\href{github.com/FPGAwars/apio}{github.com/FPGAwars/apio}}, a software suite based on project icestorm\footnote{\href{www.clifford.at/icestorm}{www.clifford.at/icestorm}} from Clifford Wolf.
\end{enumerate}

Consider to buy at Olimex Ltd. \footnote{\href{www.olimex.com}{www.olimex.com}}, the company with the highest number of registered OSHW-projects. Install the tools with:

\begin{lstlisting}[numbers=none,frame=none]
$ sudo pip install -U apio
$ apio install ice40
$ apio install iverilog
$ apio install scons
$ apio install yosys
$ sudo apt install gtkwave
$ cd build/iceprogduino
$ make
$ sudo make install
$ sudo apt install screen
\end{lstlisting}

\subsection{FPGA iCE40HX8K-EVB}

Build the project and upload the circuit design to the fpga:

\begin{enumerate}
	\item cd into the directory \lstinline|rtl| and build the project

	\begin{lstlisting}[numbers=none,frame=none]
	$ cd rtl
	$ apio clean
	$ apio build -v
	\end{lstlisting}
	
	\item Connect the fpga board with olimexino-32u4 programmer to upload the bitstream file. Use two USB cables to power both boards as shown in fig. \ref{fig:flash}.
	
	\item Upload the bitstream file to fpga board.
	
	\begin{lstlisting}[numbers=none,frame=none]
	$ cd build/rtl
	$ apio clean
	$ apio build -v
	$ apio upload
	\end{lstlisting}
\end{enumerate}

\begin{figure}
	\centering
	
	\caption{Connect programmer Olimexino-32u4 with fpga board iCE40HX8K-EVB}
	\label{fig:flash}
\end{figure}

\subsection{The USB-serial adapter}
The serial adapter BB-CH340T is used to:
\begin{enumerate}
	\item  Power MIX with 5Volt from USB cable
	\item  Serial communication to MIX over I/O Unit 16-20.
\end{enumerate}

To use USB-Serial adapter as power source we must do a little modification on the board according to Fig. \ref{fig:detail}:
\begin{enumerate}
	\item  cut with a cutter knife the connection marked in GREEN, and
	\item  solder a bridge BLACK between the right most terminal (VDD) and the 5V pad.
\end{enumerate}

This will ensure that the right most terminal connector (red cable) get's 5Volt form USB, which will be used to power the fpga board. But the UART signals (green and yellow cables) are still leveled to 3.3V, which corresponds to the in-/output signal level of fpga-connector GPIO1.

\begin{figure}
	\centering
	
	\caption{Cut the pcb track (GREEN) and solder a bridge from 5V pad to the right most connector pin.}
	\label{fig:detail}
\end{figure}

The 4 wires are connected to the GPIO connector on the right side of iCE40HX8K-EVB according to the following table. Compare with schematic in the appendix  \ref{sec:schematic}.

\begin{table}[H]
	\centering	
	\begin{tabular}{|c|c|c|}
		\hline 
		color & USB-serial & GPIO (ICE40HX8K-EVB) \\ 
		\hline 
		black & GND & 2 \\ 
		\hline 
		green & RX & 7 \\ 
		\hline 
		yellow & TX & 5 \\ 
		\hline 
		red & VDD & 1 \\ 
		\hline 
	\end{tabular} 
\end{table}

\subsection{The Go button}
We will implement the code needed by the go button proposed in  exercise 26 in chapter 1.3.1 of TAOCP (see p. 510).

\subsubsection{prepare the software}
The mixal program can be found in \lstinline|go/go.mixal|. It starts at location 4000 (which is implemented in fpga but not used by MIX). The programm spits out the welcome message. The JMP instruction at memory cell 4095 will jmp to location 0 storing a +0000 in the J-Register, because beeing a binary version with 12 bit programmcounter the next execution address without the jmp instruction would equally yield 4095 + 1 = 0000.

\lstinputlisting{../build/go/go.mixal}

First we translate the mixal programm to binary code with \lstinline|mixal/tools/asm.py|.

\begin{lstlisting}[numbers=none,frame=none]
$ cd build/go
$ ../../mixal/tools/asm.py go.mixal
$ cat go.mls
\end{lstlisting}

\lstinputlisting{../build/go/go.mls}

Next we must translate the binary code into a binary format readable by the fpga toolchain. This can be done with the python script \lstinline|mixal/tools/mls2bin.py|.

\begin{lstlisting}[numbers=none,frame=none]
$ ../../mixal/tools/mls2bin.py go.mls
$ cat go.bin
\end{lstlisting}

The python scripts reads the listing file \lstinline|go.mls|, extracts the code and writes it in the file \lstinline|go.bin|.

Inspect the binary file `go.bin`

\lstinputlisting[firstnumber=4090,linerange=4090-4096]{../build/go/go.bin}

The output contain the program code expressed as binary numbers. These binary numbers can be flashed to the iCE40HX8K-EVB board, so it will be stored permanently in the MIX computer. At every reset (press \textit{Go button}) the code will be executed. The first 4000 zero lines translate to NOP instructions. At the end you find the sequence IN(16),JBUS,JMP...

\subsection{build and flash to iCE40HX8K-EVB}

\begin{itemize}
	\item Copy the binary file \lstinline|go.bin| into the directory \lstinline|rtl|, where the fpga description files are.
	\item Rebuild the fpga project and upload. An \lstinline|apio clean| is needed, because otherwise the preloaded memory will not be updated.	
\end{itemize}

\begin{lstlisting}[numbers=none,frame=none]
$ cp go.bin ../../rtl/go.bin
$ apio clean
$ apio build -v
$ apio upload
\end{lstlisting}

\textbf{Tipp:} change the welcome message to ensure the new rom file has been uploaded.

\subsection{print toast case with a 3D printer}
In the subfolder \lstinline|build/toast| you find printing files for the case. The case consists of three parts:

\begin{itemize}
\item \lstinline|bottom.blend|: the bottom part of the case
\item \lstinline|top.blend|: top part of case
\item \lstinline|go.blend|: go bottom
\end{itemize}

\begin{figure}
	\centering
	
	\caption{MIX fits in nice toast like case}
	\label{fig:toast}
\end{figure}

\section{Example program 1.3.2.ex20T}
\label{traffic}
We will run programm \lstinline|T| of exercise 20 in chapter 1.3.2 TAOCP (p. 161) on MIX. Programm \lstinline|T| controls the traffic signal at corner of Del Mare Boulevard and Berkeley Avenue. This project will connect LEDs directly to the register rX and a push button to the  Overflow toggle. This will be done extending the fpga design and routing the appropriate signals to the GPIO connector at the back of MIX.

\begin{figure}
	\centering
	
	\caption{Connect LEDs and push button over the GPIO connector directly to register rX to control the traffic light}
	\label{fig:mixtraffic}
\end{figure}

\subsection{Extending the fpga desing}

Make a copy of the folder \lstinline|rtl| and cd into it.

\begin{lstlisting}[numbers=none,frame=none]
$ cd build
$ cp -r rtl rtl_traffic_light
$ cd rtl_traffic_light
\end{lstlisting}

\subsubsection{mix.pcf}

Find the following lines in the physical constraint file \lstinline|mix.pcf| and uncomment to get access to the GPIO pins 9-19.

\lstinputlisting[language=verilog,firstnumber=15,linerange=15-25]{../build/rtl/mix.pcf}

\subsubsection{mix.v}

To connect the Register rX with the traffic signals: find the following lines (28--38 and 47--56) in \lstinline|mix.v| and uncomment:

\lstinputlisting[language=verilog,firstnumber=20,linerange=20-56]{../build/rtl/mix.v}

Control the overflow toggle with the button by uncommenting line 239 in the code snippet:

\lstinputlisting[language=verilog,firstnumber=237,linerange=237-245]{../build/rtl/mix.v}

\subsection{rebuild and flash to iCE40HX8K-EVB}

Rebuild the fpga project and upload.

\begin{lstlisting}[numbers=none,frame=none]
$ apio clean
$ apio upload -v
\end{lstlisting}

\textbf{Tipp}: change the welcome message to ensure the new rom file has been uploaded.

\subsection{add leds and button to GPIO}
Connect leds and button (don't forget resistors) to the appropriate GPIO connectors as described in the \lstinline|mix.pcf| file. For simplicity only one LED is shown below:

\begin{figure}[H]
	\centering
	\input{schaltung_gpio_led.cir}
	\caption{connect LED and button to GPIO connector}
	\label{fig:leds}
\end{figure}

\textbf{Attention}: gpio pins 1,2,5 and 7 are already used by the internal USB-serial converter.

\subsection{t.mixal}
Compile and write \lstinline|mixal/1.3.2.ex20/t.mixal| to puching card format. Start MIX by pressing the \textit{go button}. Upload \lstinline|t.card| to MIX and see the traffic signals blinking.

\section{Service}
In case you encounter an issue with MIX:
\begin{itemize}
	\item don't panic
	\item plese send an email to the author\footnote{mi.schroeder@netcologne.de} with a precise description of the problem.
\end{itemize}

\section{License}

\subsection{mix-fpga}
The project as a whole is licensed under the GPL 3 and can be found at \href{www.gitlab.com/x653/mix-fpga}{www.gitlab.com/x653/mix-fpga}.
\subsection{manual}
\doclicenseThis

\newpage

\appendix

\section{Schematic iCE40HX8K-EVB}
\label{sec:schematic}


\section{Schematic BB-CH340T}
\label{sec:schematic}
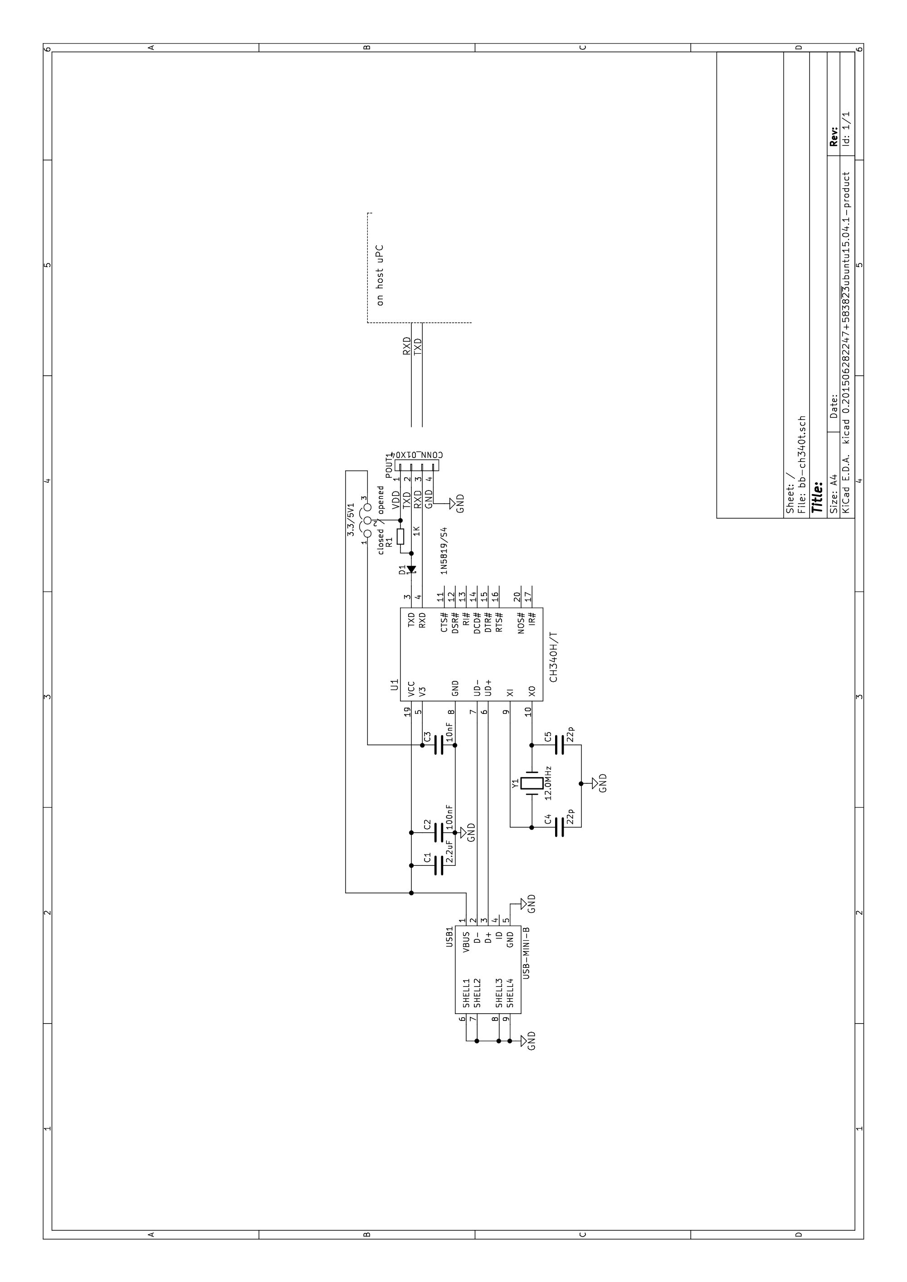
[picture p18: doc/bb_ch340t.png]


\end{document}

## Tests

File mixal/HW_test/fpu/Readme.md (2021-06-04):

## Implementation of FPU
We will implement fpu as described in TAOCP Vol. 2.
We test the hardware fpu by running a test programm on MIX, which reads 666 testvectors. Each testvector contains two aperands a,b. The MIX programm then calculates the product a*b in hardware and with the floating point assembler routines described in TAOCP Vol 2. Both results are output to tty.

We use card (80 char) as input and tty (70 char) as output. So we won't see corrupted card input due to USB delay.

### progress
Up to now FADD,FSUB and FMUL work! The timings are: 4u, 4u and 9u as required by Knuth (compare TAOCP Vol. 2)

### Testing the FPU

#### fpu_a.mixal, fpu_s.mixal, fpu_m.mixal 
This are the assembler programs to test the hardware fpu. They read testvectors containing two operands a and b. Then they calculate a+b,a-b or a*b twice. First with assembler routine according to Knuth TAOCP Vol. 2. Then with FPU in hardware.

The assembler routines of floating point arithmetic need a special command `JXO`: jump if registerX is odd.
This has been implemented in hardware as command JMP(7).

#### fpu_rand.py
The python script generates testvectors composed of two randomly  generated floating point numbers a and b.

#### prepare input
```
fpu_rand.py 666
mixasm fpu_a.mixal -l
../../tools/mls2card.py fpu_a.mls
cat fpu_a.card rand.card > fpu_a_rand.card
```
#### run the test on MIX

```
cat /dev/ttyUB0 > fpu_a.out
<in other terminal>
cat fpu_a_rand.card > /dev/ttyUSB0
```

#### Verify the output

The python script `fpu_a_ver.py` verifies the output of MIX fpu programs. `PASS: <a> * <b> = <Knuths routine> FPU <result of FPU> <accuracy compared to double precision python>`  

```
./fpu_a_ver.py fpu.out
```

All 666 Vectors passed all tests (FADD,FSUB,FMUL).

```
WELCOME TO MIX. 1U = 40NS. U16-U20 UART @115200 BAUD. U8 1000 BLOCKS  

PASS: 1.8759447E-06 * 3.6056668E-28 = 6.7640314E-34 FPU 6.7640314E-34 0.99999999
PASS: 1.7834705E+03 * 8.2148222E-19 = 1.4650892E-15 FPU 1.4650892E-15 0.99999994
PASS: 5.7147675E-19 * 4.1329526E-19 = 2.3618865E-37 FPU 2.3618865E-37 1.00000009
PASS: 4.7559501E-21 * 1.1379468E-04 = 5.4120177E-25 FPU 5.4120177E-25 0.99999990
PASS: 9.9061203E+04 * 3.2849323E-30 = 3.2540926E-25 FPU 3.2540926E-25 0.99999975
PASS: 1.3381295E-02 * 6.0713204E-16 = 8.1242139E-18 FPU 8.1242139E-18 1.00000013
PASS: 1.6356209E-22 * 4.4763898E+08 = 7.3216769E-14 FPU 7.3216769E-14 1.00000002
PASS: 6.5452131E-03 * 2.6138429E-15 = 1.7108160E-17 FPU 1.7108160E-17 1.00000007
PASS: 1.5293589E+07 * 3.3928755E+03 = 5.1889242E+10 FPU 5.1889242E+10 0.99999998
PASS: 9.4776714E-01 * 2.1717965E+08 = 2.0583571E+08 FPU 2.0583571E+08 0.99999990
PASS: 1.0007590E-01 * 1.8778110E-26 = 1.8792362E-27 FPU 1.8792362E-27 0.99999996
PASS: 1.1125302E-26 * 9.6329599E-31 = 1.0716966E-56 FPU 1.0716966E-56 1.00000062
...

```

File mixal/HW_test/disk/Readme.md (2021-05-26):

## Testing U8 on MIX
We will test U8 on MIX. The SRAM chip on the iCE40HX8K-EVB board is used as an external memory accesible as unit U8. Its 512kByte translate to 1000 blocks a 100 words (31 bits). The memory is not persistent. It holds data for the time the board is connected to power supply (over USB) even after pressing the go button (reset)

### write data to disk U8
#### w.mixal
First we will write 3996 randomly filled punched cards into memory (3996 punched cards is the equivalent of 666 data blocks of U8). The mixal program can be found in `w.mixal`:

Inpect the file with:
```
cat w.mixal
```

```
BUFFER	EQU		2000
		ORIG	1000
BEGIN	ENTX		
WRITE	IN		BUFFER(16)
		IN		BUFFER+16(16)
		IN		BUFFER+32(16)
		IN		BUFFER+48(16)
		IN		BUFFER+64(16)
		IN		BUFFER+80(16)
		JBUS	*(16)
		OUT		BUFFER(8)
		INCX	1
		CMPX	MAX
		JL		WRITE
		HLT	
MAX		CON		666
		END		BEGIN
```

#### w.mls
First we translate the mixal programm to binary code. This is done with the GNU library `mixasm`. The option `-l` produces a list file `w.mls`

```
mixasm w.mixal -l
cat w.mls
```
```
*** w.mixal: Kompilerzusammenfassung ***

-----------------------------------------------------------------
Src     Address  Compiled word           Symbolic rep
-----------------------------------------------------------------
004     01000   + 00 00 00 02 55 	ENTX	0,0
005     01001   + 31 16 00 16 36 	IN	2000,0(2:0)
006     01002   + 31 32 00 16 36 	IN	2016,0(2:0)
007     01003   + 31 48 00 16 36 	IN	2032,0(2:0)
008     01004   + 32 00 00 16 36 	IN	2048,0(2:0)
009     01005   + 32 16 00 16 36 	IN	2064,0(2:0)
010     01006   + 32 32 00 16 36 	IN	2080,0(2:0)
011     01007   + 15 47 00 16 34 	JBUS	1007,0(2:0)
012     01008   + 31 16 00 08 37 	OUT	2000,0(1:0)
013     01009   + 00 01 00 00 55 	INCX	1,0
014     01010   + 15 53 00 05 63 	CMPX	1013,0
015     01011   + 15 41 00 04 39 	JL	1001,0
016     01012   + 00 00 00 02 05 	HLT	0,0
017     01013   + 00 00 00 10 26 	CON	0666
-----------------------------------------------------------------

*** Startadresse:	1000
*** Endadresse:	1014

*** Symboltabelle
BEGIN               :  1000
MAX                 :  1013
BUFFER              :  2000
WRITE               :  1001

*** Ende der Zusammenfassung ***
```
#### w.card
Next we must write the binary code onto punchcards. This can be done with the python script `tools/mls2card.py`.

```
../../tools/mls2card.py w.mls
```

The python scripts reads the listing file `w.mls`, extracts the code and writes it in the file `w.card`.

Inspect the punchcards

```
cat w.card
```
Every line holds 80 chars of a card. The first to cards contain the bootloader discussed in exercise 26 in chapter 1.3.1 of TAOCP (see p. 510). The last cards is the so called transfer card, which tells the bootloader to start execution at memory location 1000.

```
 O O6 Z O6    I C O4 0 EH A  F F CF 0  E   EU 0 IH G BB   EJ  CA. Z EU   EH E BA
   EU 2A-H S BB  C U 1AEH 2AEN V  E  ABG  CLU Z EH E BB J B. A  9               
00002710000000000183052428906005284833640532677668053687197205410662760545260580
00000710070263980066052428854900002621990265552255026240643900000001330000000666
TRANS010000000000000000000000000000000000000000000000000000000000000000000000000
```
#### random punched cards
Now we build 3996 random punched cards and add them as input to the program cards.

```
./randcard.py
cat w.card rand.card > wr.card
```

#### go
Power MIX with USB cable connected to your computer.

Start a screen session with 115200 baud (8N1)

```
screen /dev/ttyUSB0 115200
```

Press the "Go button" on MIX

You should see the welcome message on your terminal:

```
WELCOME TO MIX. 1U = 30NS. U19 @115200 BAUD (8N1).                    
```

#### input the cards to U16
You can send the punch cards to MIX within the screen terminal session.

1. Read cards into a screen-buffer (called p) 

```
<in screen terminal> Ctr-a : readreg w wr.card <enter>
```

2. Send buffer to MIX
	
```
<in screen terminal> Ctrl-a : paste w <enter>
```

This will take a while!

### read the cards from disk U8

Now we will try to retrieve the data.
#### r.mixal
`r.mixal` will read the disk U8 and output the data to USB-serial.

Inpect the file with:
```
cat r.mixal
```

```
BUFFER	EQU	2000
	ORIG	1000
BEGIN 	ENTX 	0
READ	IN	BUFFER(8)
	OUT	BUFFER(17)
	OUT	BUFFER+16(17)
	OUT	BUFFER+32(17)
	OUT	BUFFER+48(17)
	OUT	BUFFER+64(17)
	OUT	BUFFER+80(17)
	JBUS	*(17)
	INCX	1
	CMPX	MAX
	JL	READ
	HLT
MAX	CON	666
	END	BEGIN

```

#### r.mls
First we translate the mixal programm to binary code. This is done with the GNU library `mixasm`. The option `-l` produces a list file `w.mls`

```
mixasm r.mixal -l
cat r.mls
```
```
*** r.mixal: Kompilerzusammenfassung ***

-----------------------------------------------------------------
Src     Address  Compiled word           Symbolic rep
-----------------------------------------------------------------
004     01000   + 00 00 00 02 55 	ENTX	0,0
005     01001   + 31 16 00 08 36 	IN	2000,0(1:0)
006     01002   + 31 16 00 17 37 	OUT	2000,0(2:1)
007     01003   + 31 32 00 17 37 	OUT	2016,0(2:1)
008     01004   + 31 48 00 17 37 	OUT	2032,0(2:1)
009     01005   + 32 00 00 17 37 	OUT	2048,0(2:1)
010     01006   + 32 16 00 17 37 	OUT	2064,0(2:1)
011     01007   + 32 32 00 17 37 	OUT	2080,0(2:1)
012     01008   + 15 48 00 17 34 	JBUS	1008,0(2:1)
013     01009   + 00 01 00 00 55 	INCX	1,0
014     01010   + 15 53 00 05 63 	CMPX	1013,0
015     01011   + 15 41 00 04 39 	JL	1001,0
016     01012   + 00 00 00 02 05 	HLT	0,0
017     01013   + 00 00 00 10 26 	CON	0666
-----------------------------------------------------------------

*** Startadresse:	1000
*** Endadresse:	1014

*** Symboltabelle
BEGIN               :  1000
MAX                 :  1013
BUFFER              :  2000
READ                :  1001

*** Ende der Zusammenfassung ***
```
#### r.card
Next we must write the binary code onto punchcards. This can be done with the python script `tools/mls2card.py`.

```
../../tools/mls2card.py r.mls
```

The python scripts reads the listing file `w.mls`, extracts the code and writes it in the file `r.card`.

Inspect the punchcards

```
cat r.card
```
Every line holds 80 chars of a card. The first to cards contain the bootloader discussed in exercise 26 in chapter 1.3.1 of TAOCP (see p. 510). The last cards is the so called transfer card, which tells the bootloader to start execution at memory location 1000.

```
 O O6 Z O6    I C O4 0 EH A  F F CF 0  E   EU 0 IH G BB   EJ  CA. Z EU   EH E BA
   EU 2A-H S BB  C U 1AEH 2AEN V  E  ABG  CLU Z EH E BB J B. A  9               
00002710000000000183052428854805242891250528483429053267773305368720370541066341
00000710070545260645026424227400002621990265552255026240643900000001330000000666
TRANS010000000000000000000000000000000000000000000000000000000000000000000000000
```

#### go second time
Use the old screen session or start a new one.
```
screen /dev/ttyUSB0 115200
```

Press the "Go button" on MIX

You should see the welcome message on your terminal (again)

```
WELCOME TO MIX. 1U = 30NS. U19 @115200 BAUD (8N1).                    
```

#### input the r.card to U16
You can send the punch cards to MIX within the screen terminal session.

1. Read cards into a screen-buffer (called r) 

```
<in screen terminal> Ctr-a : readreg r r.card <enter>
```

2. Send buffer to MIX
	
```
<in screen terminal> Ctrl-a : paste r <enter>
```

This will take a while! But you should see the retreived random punched cards.

### check memory
To check memory you could retrieve the cards by piping them into a new file:

```
cat /dev/ttyUSB0 > mem.out
```

Then check with diff the integrity. Option -w ommites the whitespaces is good because, the terminal generates extra carriage returns (char13) which will be missed in the rand.card file. (At least on *ix computers). 
```
diff -w mem.out rand.card
```
will output
```
1d0
< WELCOME TO MIX. 1U = 40NS. U16-U20 UART @115200 BAUD. U8 1000 BLOCKS  
```

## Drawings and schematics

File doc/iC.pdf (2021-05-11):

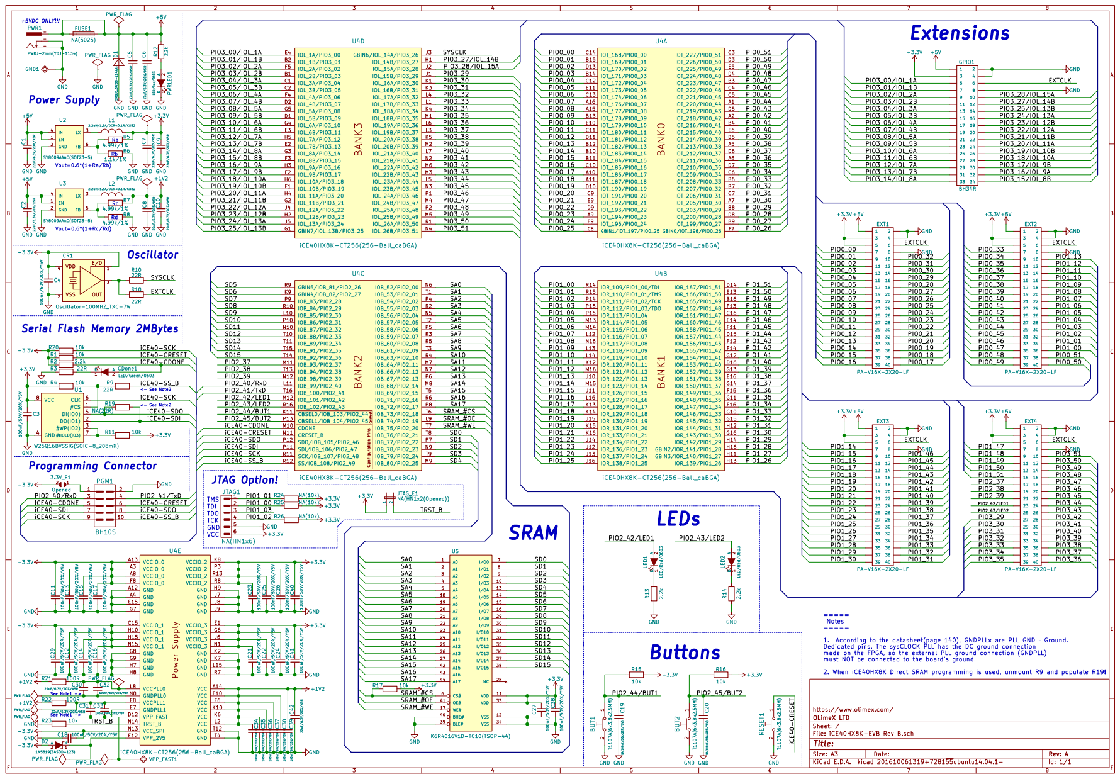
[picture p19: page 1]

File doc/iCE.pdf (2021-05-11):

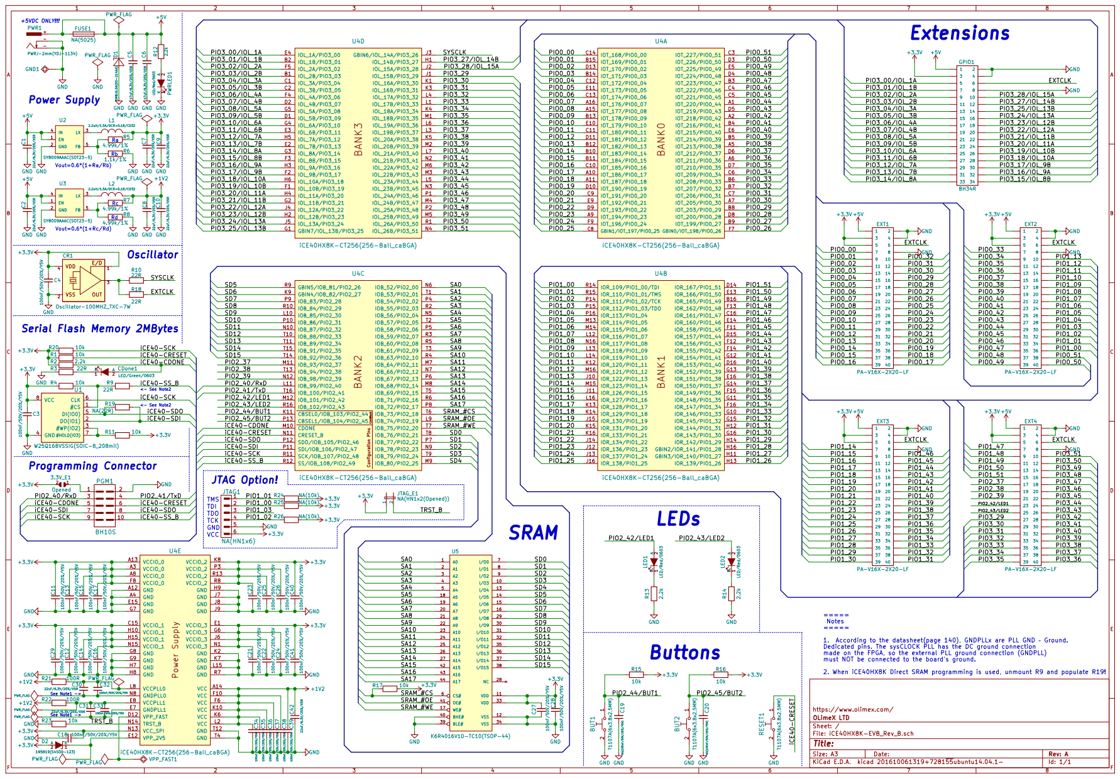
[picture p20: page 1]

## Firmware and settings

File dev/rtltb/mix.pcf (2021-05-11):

# physical constrain file
# assign io-pins to pin numbering of iCE40-HX1K on olimex board iCE40-HX1K-EVB
# compare to the schematic of the board and the datasheet of fpga
# to use internal pullup set (-pullup yes)

set_io clk_in J3  	# clk in 100 MHz
set_io but[0] K11 	# BUT1 on board
set_io but[1] P13 	# BUT2 on board
set_io hlt M12 		# LED1 on board
set_io led[1] R16 	# LED2 on board

#at the GPIO connector you find
set_io rx 	E4	# GPIO 5
set_io tx 	B2	# GPIO 7
#set_io dmred 	F5	# GPIO 9
#set_io bred 	J2	# GPIO 10
#set_io dmamber 	B1	# GPIO 11
#set_io bamber 	H1	# GPIO 12
#set_io dmgreen 	C1	# GPIO 13
#set_io bgreen 	G1	# GPIO 14
#set_io dmdw 	C2	# GPIO 15
#set_io bdw 	J5	# GPIO 16
#set_io dmw 	F4	# GPIO 17
#set_io bw 	H2	# GPIO 18
#set_io button 	D2	# GPIO 19
#set_io gpio20 	J4	# GPIO 20
#set_io gpio21 	G5	# GPIO 21
#set_io gpio22 	G2	# GPIO 22
#set_io gpio23 	D1	# GPIO 23
#set_io gpio24 	H4	# GPIO 24
#set_io gpio25 	G4	# GPIO 25
#set_io gpio26 	F1 	# GPIO 26
#set_io gpio27 	E3	# GPIO 27
#set_io gpio28	H6	# GPIO 28
#set_io gpio29 	H5	# GPIO 29
#set_io gpio30 	F2 	# GPIO 30
#set_io gpio31 	E2	# GPIO 31
#set_io gpio32 	H3 	# GPIO 32
#set_io gpio33 	G3 	# GPIO 33
#set_io gpio34 	F3	# GPIO 34


# the following pins refer to the SRAM chip on the iCE40HX8K-EVB board
# the plan is to use SRAM as U1-U15 I/O block device
set_io sram_addr[0] N6
set_io sram_addr[1] T1
set_io sram_addr[2] P4
set_io sram_addr[3] R2
set_io sram_addr[4] N5
set_io sram_addr[5] T2
set_io sram_addr[6] P5
set_io sram_addr[7] R3
set_io sram_addr[8] R5
set_io sram_addr[9] T3
set_io sram_addr[10] R4
set_io sram_addr[11] M7
set_io sram_addr[12] N7
set_io sram_addr[13] P6
set_io sram_addr[14] M8
set_io sram_addr[15] T5
set_io sram_addr[16] R6
set_io sram_addr[17] P8

set_io sram_cen T6
set_io sram_oen L9
set_io sram_wen T7

set_io sram_data[0] T8
set_io sram_data[1] P7
set_io sram_data[2] N9
set_io sram_data[3] T9
set_io sram_data[4] M9
set_io sram_data[5] R9
set_io sram_data[6] K9
set_io sram_data[7] P9
set_io sram_data[8] R10
set_io sram_data[9] L10
set_io sram_data[10] P10
set_io sram_data[11] N10
set_io sram_data[12] T10
set_io sram_data[13] T11
set_io sram_data[14] T15
set_io sram_data[15] T14

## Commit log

2021-04-08 mixal assembler -> binary
2021-05-02 halt led, go button, case build, p and e working
    [bottom-Cube.stl, bottom.blend, bottom1.blend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]
2021-05-05 traffic lights running
    [bottom-Cube.stl, bottom.blend, bottom1.blend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]
2021-05-06 out U16-U20 with different word sizes
    [bottom-Cube.stl, bottom.blend, go1.blend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]
2021-05-06 added details
    [bottom-Cube.stl, bottom.blend, go-Cube.stl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]
2021-05-06 led Readme
2021-05-13 3d files
    [go-Cube.stl, go.blend, go1.blend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]
2021-07-09 1.4.3.2T trace routine (uses magnetic tape U0)
2021-07-12 added mix and go assembler (Peterson)
2023-07-14 added Makefile using oss-cad-suite
2023-07-14 added hardware.bin in case a newer toolchain builds a design that does not fit into HX8K
